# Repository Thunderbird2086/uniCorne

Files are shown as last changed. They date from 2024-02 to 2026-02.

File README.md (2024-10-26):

# uniCorne

uniCorne is inspired by [corne](foostatn/crkbd), and here are the key features of uniCorne:

1. **Controller Compatibility**: uniCorne is specifically tailored to work with ProMicro-like controllers such as [Nice!Nano](https://nicekeyboards.com/docs/nice-nano/), [Elite-Pi](https://docs.keeb.io/elite-pi-guide), and [Ble Micro Pro](https://sekigon-gonnoc.github.io/BLE-Micro-Pro/#/). This ensures seamless integration and optimal performance.
1. **Hardware Handedness**: Unlike many other keyboards, uniCorne supports hardware handedness for ProMicro-like RP2040 controller boards. This flexibility allows users to choose their preferred orientation without sacrificing functionality.
1. **Nice!View Integration**: uniCorne has been meticulously crafted to seamlessly integrate with [Nice!View](https://nicekeyboards.com/docs/nice-view/). Users can enjoy a cohesive experience without needing any modifications to the board.

In summary, uniCorne combines controller compatibility, hardware flexibility, and thoughtful integration, making it a standout choice for keyboard enthusiasts.

## Profiles
uniCorne offers three distinct flavors: standard profile, low profile, and hybrid profile.

### Standard Profile
Equipped with Cherry MX compatible switches, available in both 3-pin and 5-pin.<br>
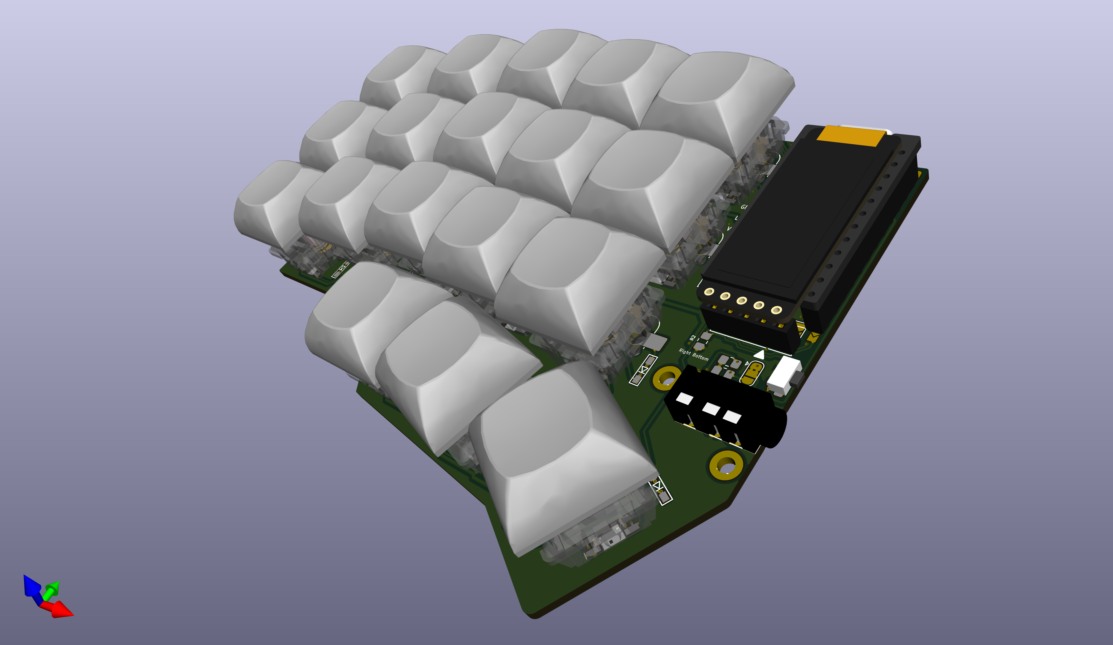
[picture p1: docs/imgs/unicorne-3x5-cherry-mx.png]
Standard Profile


### Low Profile
The low-profile variant primarily incorporates Kailh Low-Profile switches, supporting both Kailh Choc V1 and V2 switches.<br>
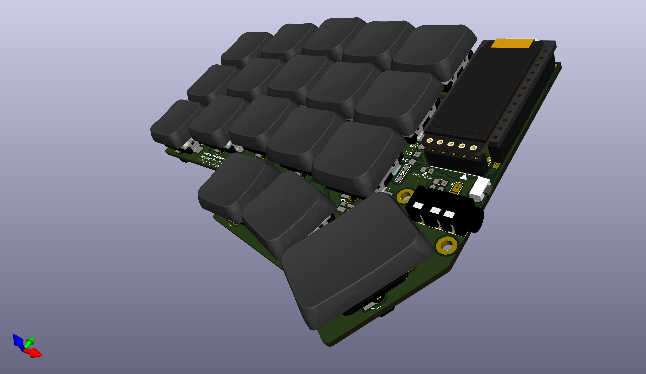
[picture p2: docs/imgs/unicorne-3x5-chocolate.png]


### Hybrid Profile
In the hybrid setup, low-profile switches are utilized for the thumb block, while standard-profile switches are employed for the remaining keys.<br>
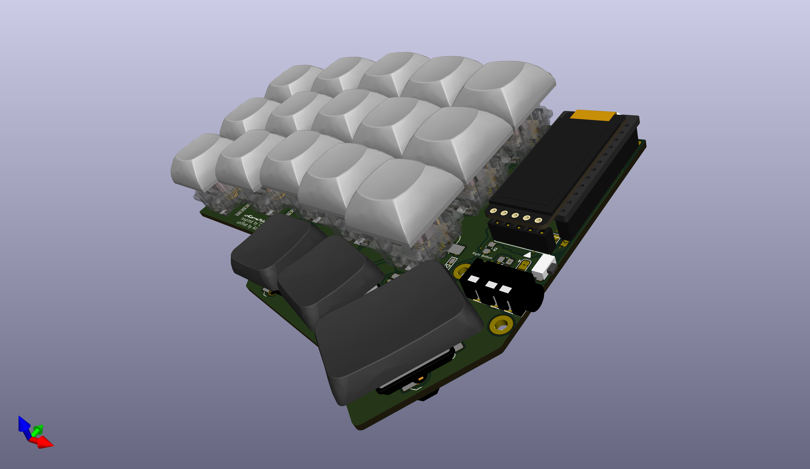
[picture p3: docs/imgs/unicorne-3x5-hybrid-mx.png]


## Variants
uniCorne is availabe in two enticing variations: 3x5 and 3x6.

The 3x6 variant caters to users who may not be accustomed to split keyboards, as its layout closely resembles that of standard keyboards. With 21 keys on each side, the 3x6 configuration boasts a total of 42 keys.<br>
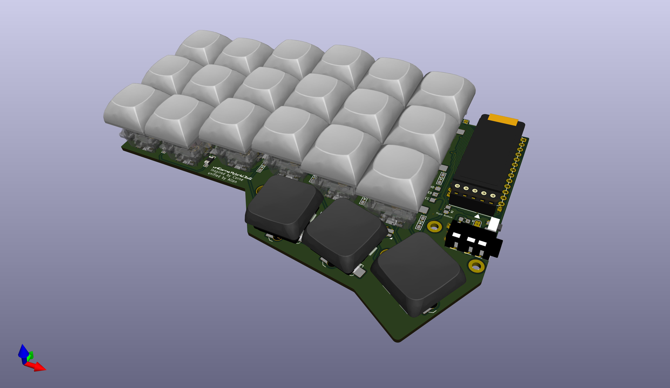
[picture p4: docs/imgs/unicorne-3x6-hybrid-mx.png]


On the other hand, the 3x5 variant provides a more streamlined option, with 18 keys on each side for a total of 36 keys.

## Build Guides
uniCorne 3x5 is used as an example. Refer to [the guides](https://thunderbird2086.github.io/uniCorne).

## fonts
 - [Android Robot](https://www.1001freefonts.com/android-robot.font)
 - [Avenir Next Heavy](https://en.maisfontes.com/avenir-next-heavy.font)
 - [Hack](https://www.1001freefonts.com/hack.font)

## firmwares
 - [QMK](https://github.com/Thunderbird2086/tb2086-qmk)
 - [ZMK](https://github.com/Thunderbird2086/unicorne-zmk-config)

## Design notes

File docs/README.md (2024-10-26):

# uniCorne Build Guide

## Materials Needed: 
- Common parts

  | **Component**        | **Quantity** | **Description**                                      |
  |---                   |---:          | ---                                                  |
  | PCB                  | 2            | Left and right side                                  |
  | Switches             | 36           | Mechanical switches (e.g., Cherry MX, Kailh Choc)    |
  | Keycaps              | 36           | Keycaps compatible with your switches                |
  | Hotswap Sockets      | 36           | Hotswap sockets compatible with your switches        |
  | 1N4148W SOD-123      | 36           | Diodes for each switch                               |
  | Tactile Push Button  | 1            | SMD 2x4x3.5mm                                        |
  | Top Plate            | 1            | Case compatible with uniCorne-3x5 PCB                |
  | Bottom Plate         | 1            | Plate compatible with uniCorne-3x5 PCB               |
  | M2x4 Screw           | 20           | Screws for assembling the case                       |
  | M2x6 Standoff        | 10           | Spacers for assembling the case                      |

- Wired or Wireless
  - Wired keyboard

    | **Component**        | **Quantity** | **Description**                                      |
    |---                   |---:          | ---                                                  |
    | MCU                  | 2            | Promicro-ish e.g. Promicro, Elite-Pi, etc.           |
    | TRRS Sockets         | 2            | For connecting the two halves of keyboard            |
    | TRRS Cable           | 1            | Cable to connect the two halves of keyboard          |

  - Wireless keyboard

    | **Component**        | **Quantity** | **Description**                                      |
    |---                   |---:          | ---                                                  |
    | MCU                  | 2            | Promicro-ish NRF52480 board e.g. [nice!nano](https://nicekeyboards.com/nice-nano)           |
    | MSK-12C02 SMD        | 2            | Power switch for wireless                            |
    | Pico-EZmate 78171 2P | 2            | 2P socket for battery                                |

- Optional parts<br>

  | **Component**        | **Quantity** | **Description**                                        |
  |---                   |---:          | ---                                                    |
  | OLED Screen          | 1            | For displaying information, 128x32                     |
  | Tenting Kit          | 1            | For ergonomic typing angle                             |

  - Wired keyboard

    | **Component**        | **Quantity** | **Description**                                      |
    |---                   |---:          | ---                                                  |
    | SK6812 mini-e        | 30           | For per-key LED                                      |
    | SK6812 mini 3535     | 6            | For backlight LED                                    |
    | 10k SMD2012(metric)  | 2            | For handedness for wired keyboard                    |
    | 4.7k SMD2012(metric) | 2            | For I2C communication for wired keyboard             |

## Step-by-Step Guide:
1. Before starting:<br>
   uniCorne is designed to be soldered only on the bottom side.
1. Align PCBs:<br>
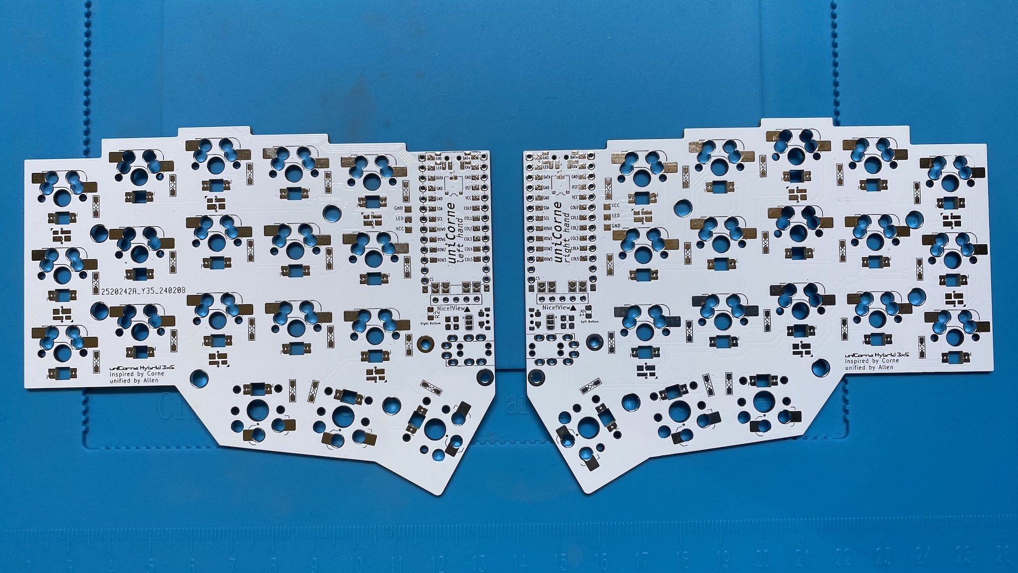
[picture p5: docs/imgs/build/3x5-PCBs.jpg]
PCBs
   <br>
   Theres is a marking on top side indicating the correct side.<br>
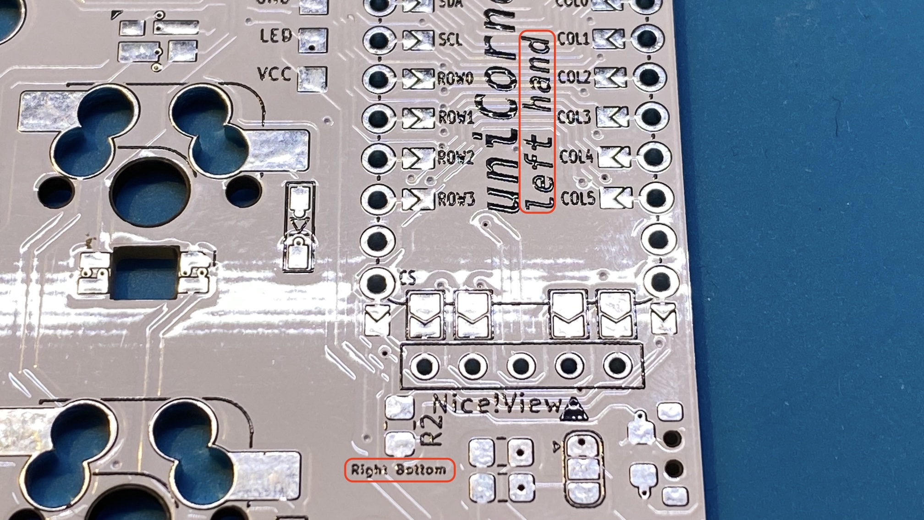
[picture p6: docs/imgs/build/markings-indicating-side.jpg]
Markings indicating side
   
1. Hotswaps:<br>
   Place the hot-swappable sockets on the PCB, and make sure it align with the holes on the PCB. Then, solder it.<br>
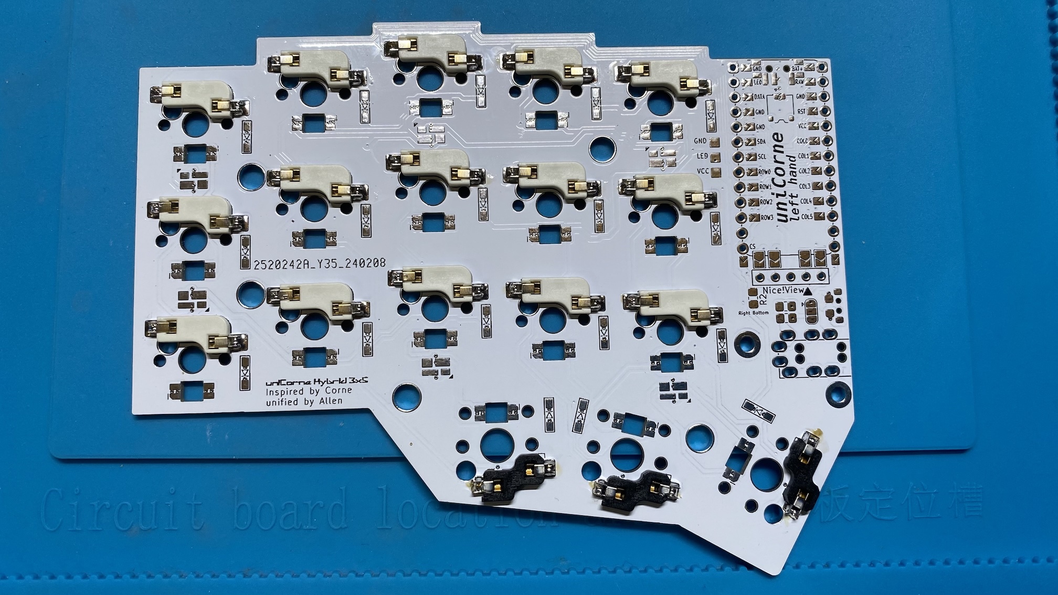
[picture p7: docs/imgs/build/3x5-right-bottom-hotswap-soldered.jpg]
Hotswap soldered
   
1. Diodes:<br>
   Diodes have markings to indicate the direction.  Make sure they are aligned with slikscreen.<br>
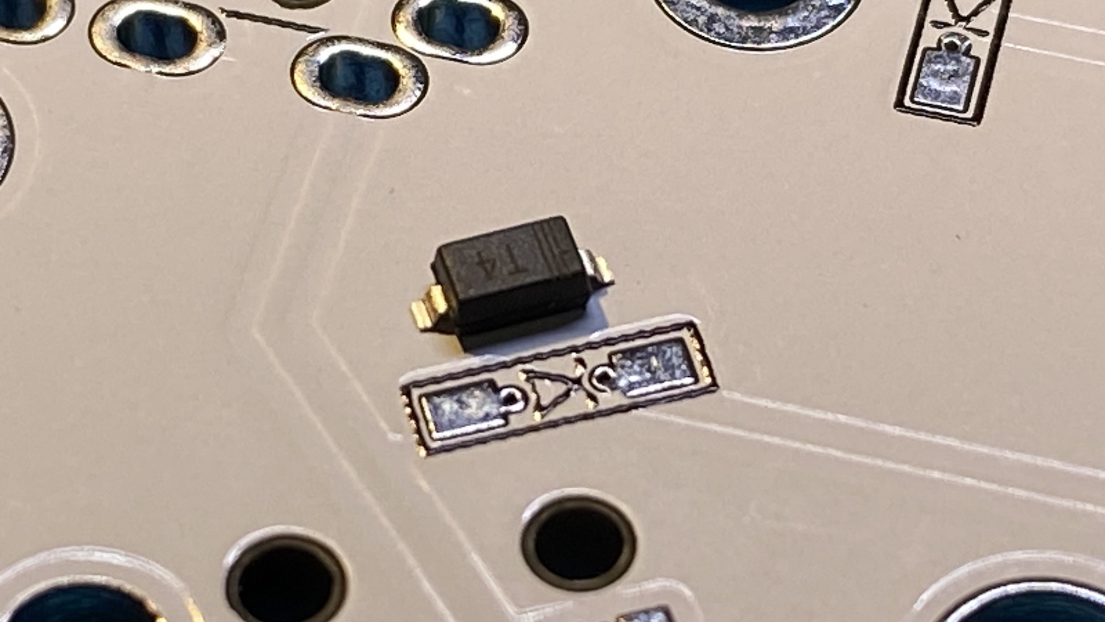
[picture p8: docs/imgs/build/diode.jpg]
diode marking
   
1. MCU
   1. Solder jumpers for MCU on the bottom side.<br>
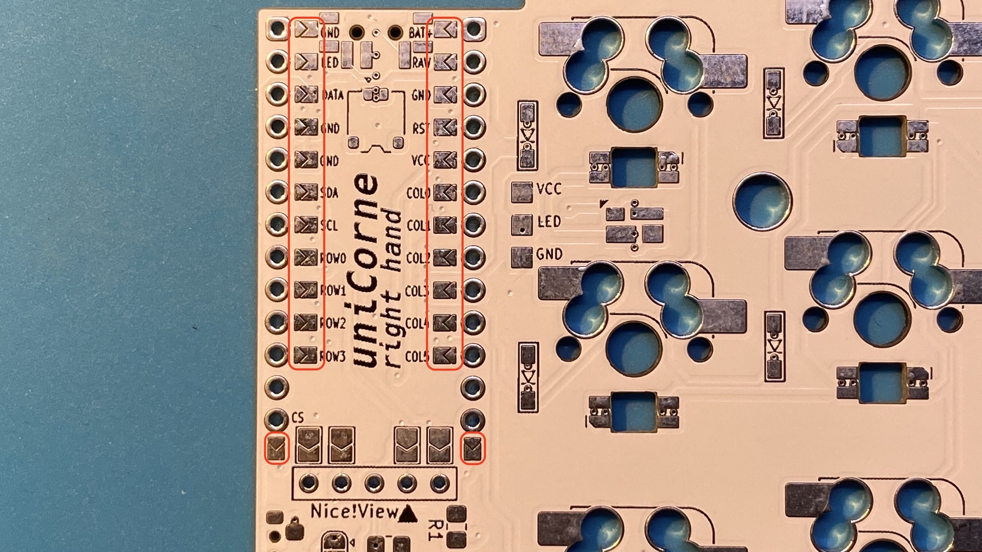
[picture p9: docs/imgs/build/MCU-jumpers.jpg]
MCU jumbers
      
   1. Solder pin sockets which allows you to replace MCUs later.<br>
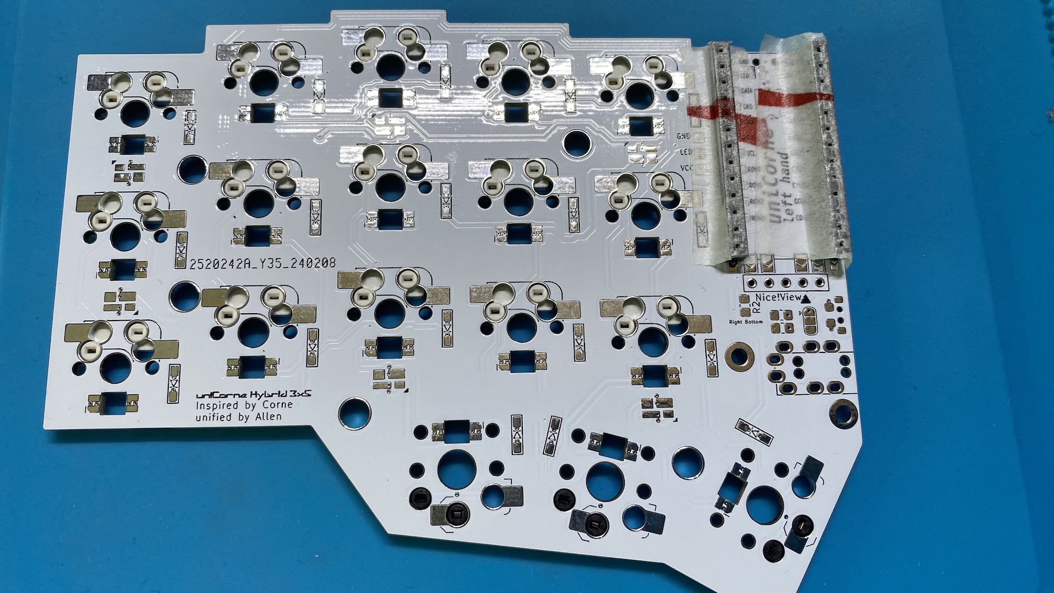
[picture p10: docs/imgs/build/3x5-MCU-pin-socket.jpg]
MCU pin sockets
      
   1. Place the MUC on pin sockets and insert pin headers.<br>
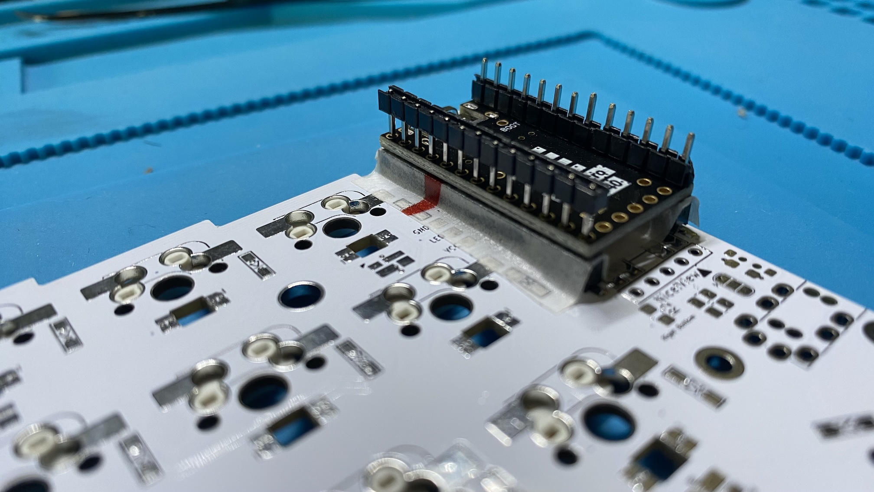
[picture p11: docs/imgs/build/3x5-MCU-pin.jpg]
      
   1. Cut the pin header for one side once everything is aligned.<br>
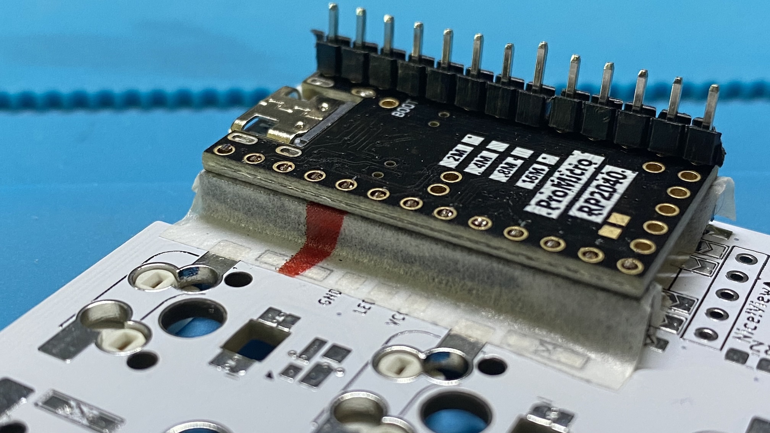
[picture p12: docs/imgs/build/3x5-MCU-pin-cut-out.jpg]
      
   1. Solder one side and repeat for the other side. The result should look like this when done.<br>
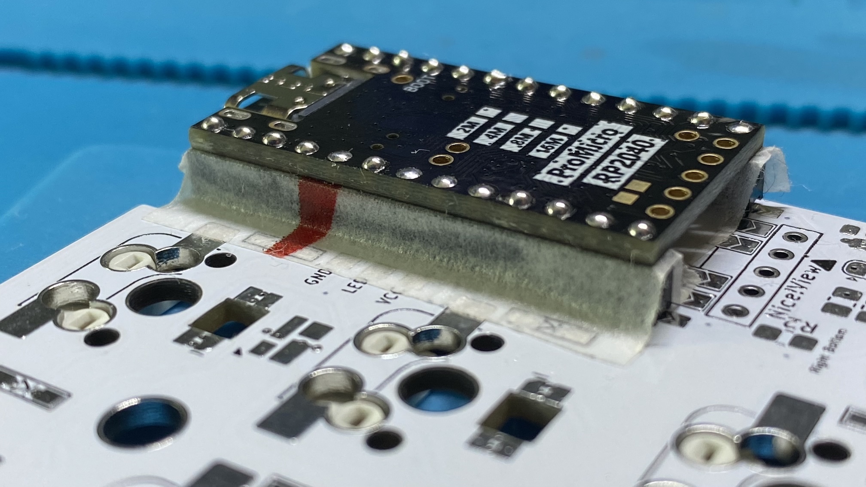
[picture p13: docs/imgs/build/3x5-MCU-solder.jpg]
MCU soldered
      
1. TRRS Socket:<br>
   Solder TRRS socket.<br>
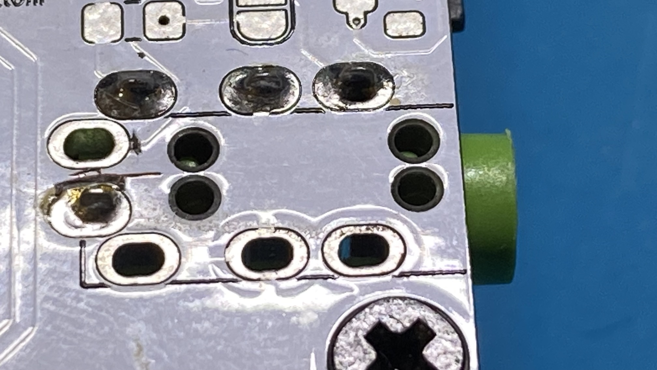
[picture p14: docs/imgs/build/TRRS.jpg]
   
1. Test the PCB:<br>
   Before fully assembling, test the PCB to ensure all switches work correctly after installing the relavant [firmware](https://github.com/Thunderbird2086/tb2086-qmk/releases). You can use a keyboard tester software for this e.g. QMK Toolbox.
1. Optional parts:
   - LEDs:<br>
     Solder LEDs.  There are two types: one for per-key lighting and the other for backlighting.<br>
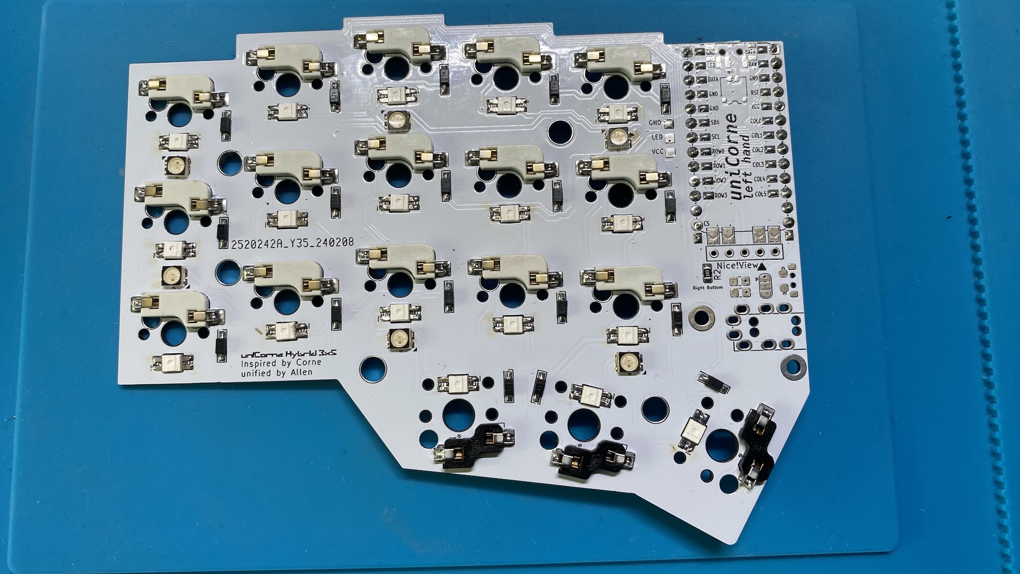
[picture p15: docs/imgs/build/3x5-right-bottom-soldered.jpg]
LEDs
     
   - OLED Screen:<br>
     If you have an OLED screen, solder jumpers for OLED as well as 5-pin socket on the bottom side.<br>
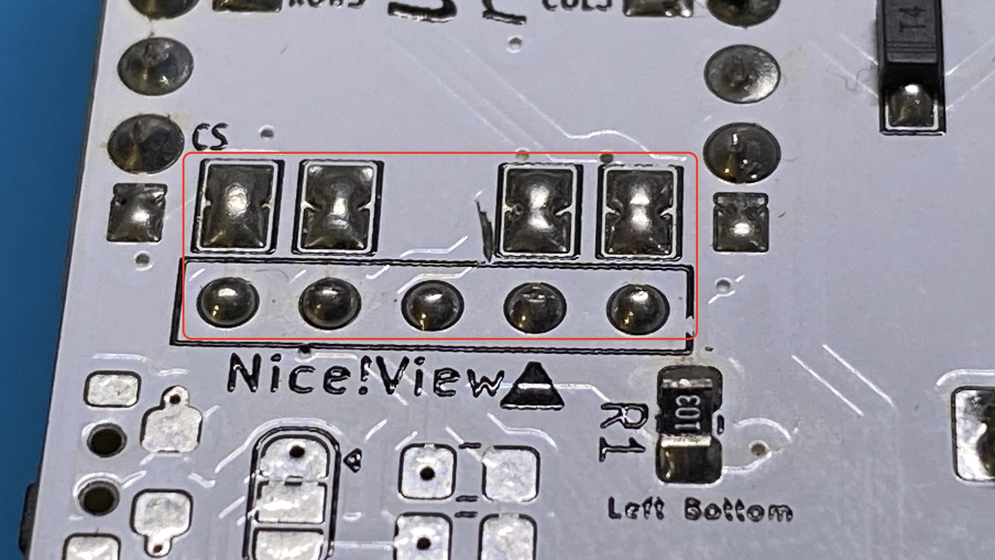
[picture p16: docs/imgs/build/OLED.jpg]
OLED
     
   - Hardware Handedness:<br>
     If you want to use hardware handedness, solder the handedness resitor on the bottom side.<br>
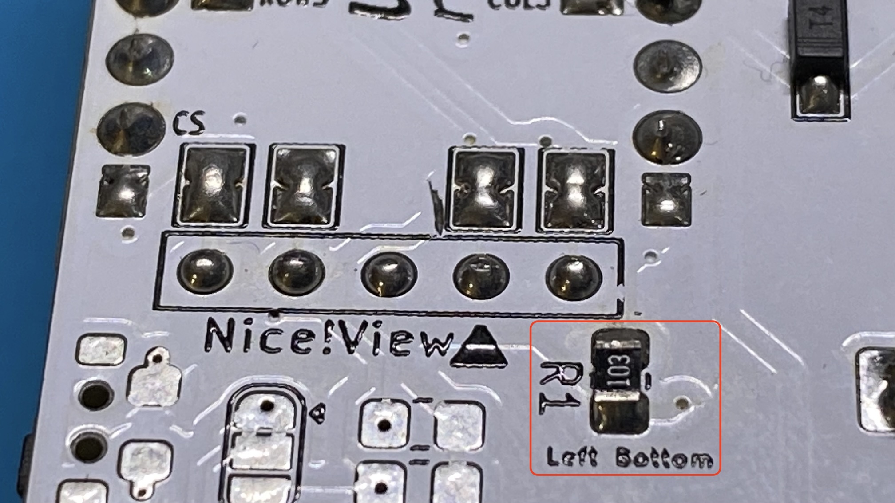
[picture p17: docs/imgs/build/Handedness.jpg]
Hardware Handedness
     
1. Assemble:<br>
   Place top plate, the PCB, and the bottom plate. Then, secure them with screws.
1. Add Keycaps:<br>
   Place your keycaps onto the switches. Ensure they are firmly seated.
1. Install Tenting Kit (optional):<br>
   If you have a tenting kit, attach it to the bottom of the case for an ergonomic typing angle.
1. Final Check:<br>
   Double-check all connections and ensure everything is securely in place.<br>
   Test the keyboard again to ensure all keys are functioning properly.
1. Enjoy Your New Keyboard:<br>
   Customize your keymap and enjoy typing on your new uniCorne-3x5 keyboard!

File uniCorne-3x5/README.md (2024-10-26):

# uniCorne 3x5

* cherry-mx-reversible : Standard Profile<br>
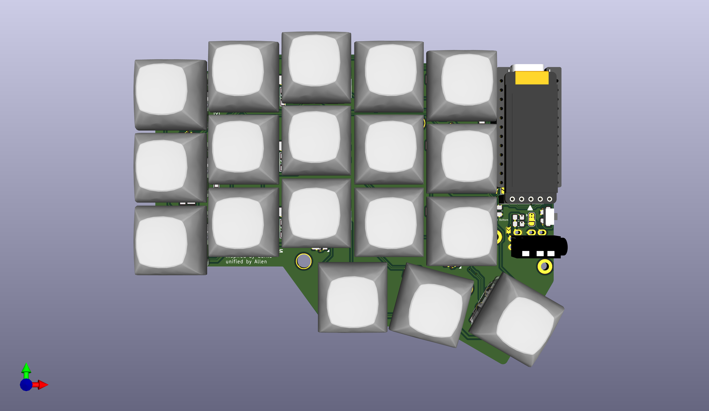
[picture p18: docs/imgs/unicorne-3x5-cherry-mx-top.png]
  

* chocolate-reversible : Low Profile<br>
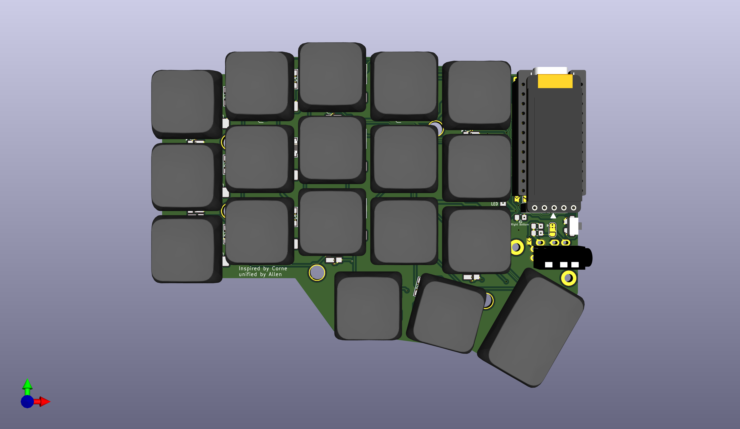
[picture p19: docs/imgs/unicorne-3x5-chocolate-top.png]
  

* mybrid-mx-reversible : Hybrid Profile<br>
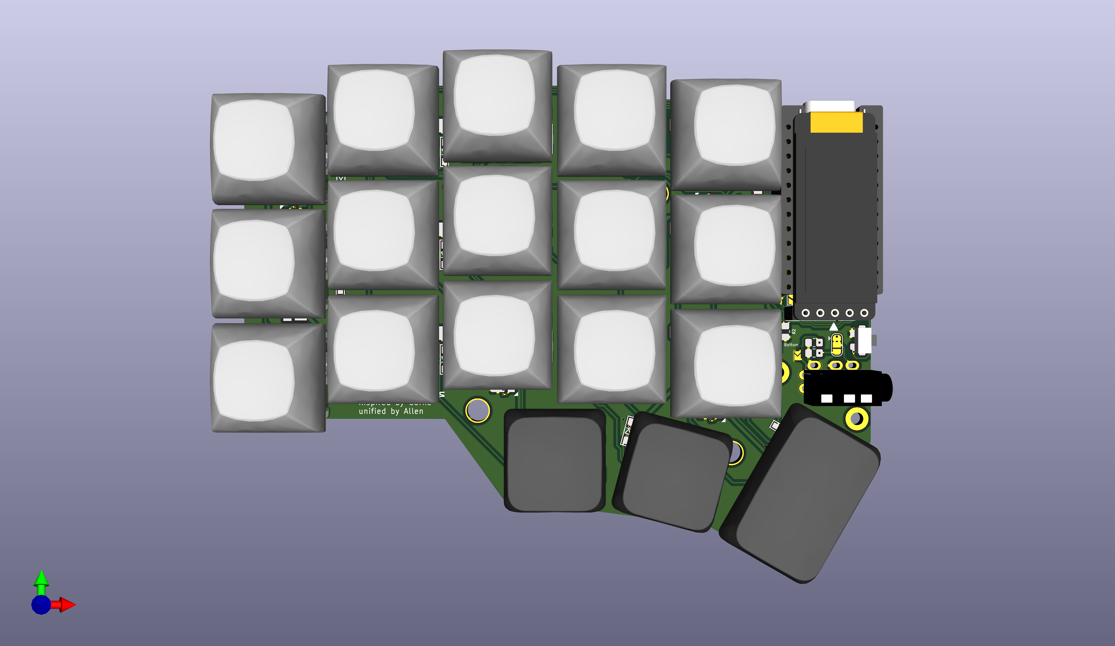
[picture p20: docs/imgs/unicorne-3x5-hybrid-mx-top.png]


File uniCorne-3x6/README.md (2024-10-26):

# uniCorne 3x6

* cherry-mx-reversible : Standard Profile<br>
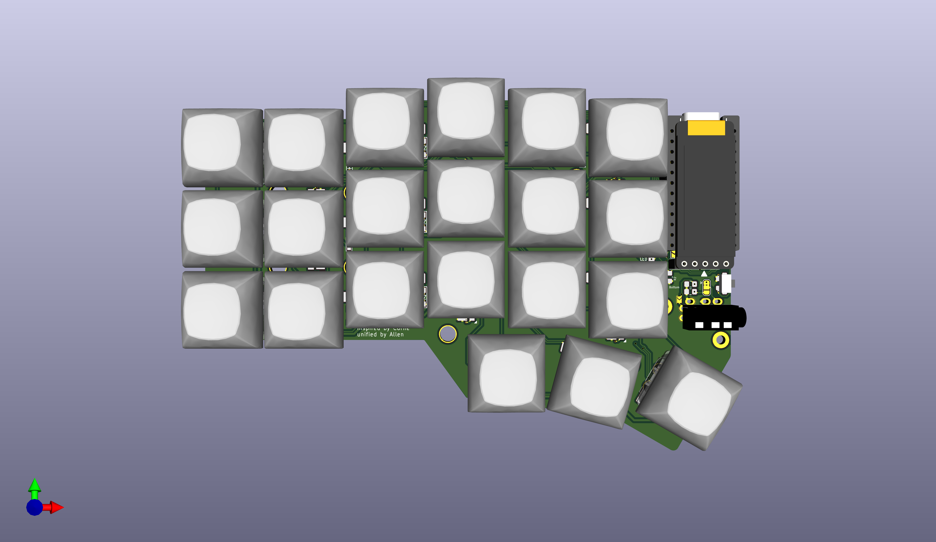
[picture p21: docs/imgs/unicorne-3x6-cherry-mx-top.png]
  

* chocolate-reversible : Low Profile<br>
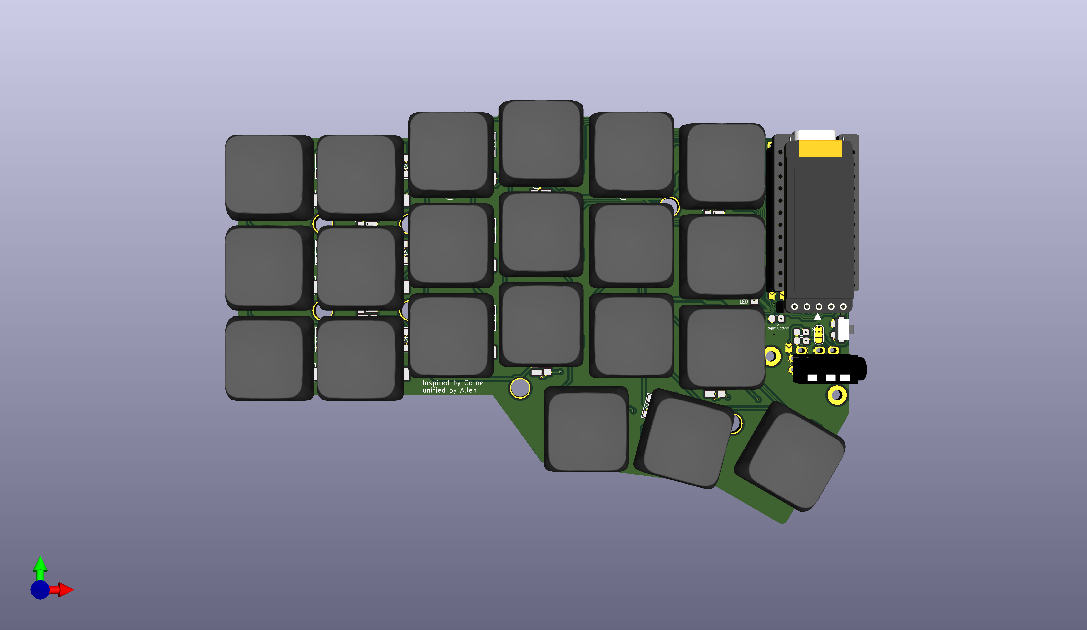
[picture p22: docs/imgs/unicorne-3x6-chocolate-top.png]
  

* mybrid-mx-reversible : Hybrid Profile<br>
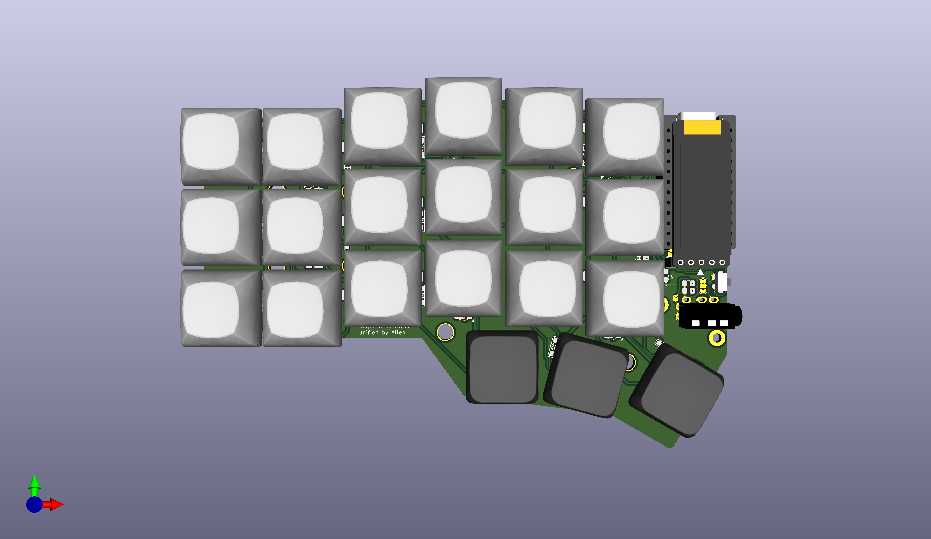
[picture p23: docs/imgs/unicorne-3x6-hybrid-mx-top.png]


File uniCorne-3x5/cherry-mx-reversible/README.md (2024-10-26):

# uniCorne 3x5 Standard Profile

## Top
uniCorne 3x5 Standard Profile Top

## Bottom
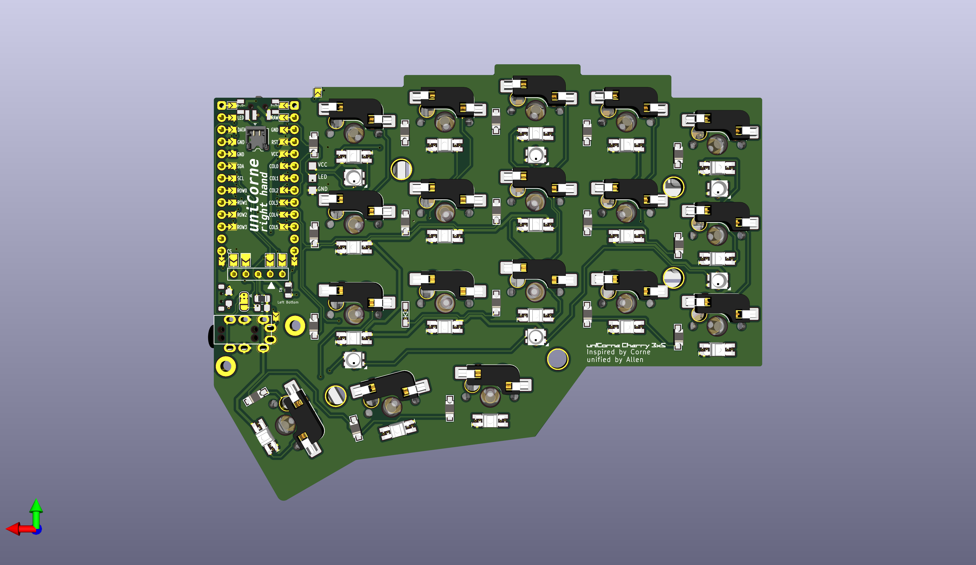
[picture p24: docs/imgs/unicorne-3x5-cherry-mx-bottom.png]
uniCorne 3x5 Standard Profile Top


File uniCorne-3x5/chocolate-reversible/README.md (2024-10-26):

# uniCorne 3x5 Low Profile

## Top
uniCorne 3x5 Low Profile Top

## Bottom
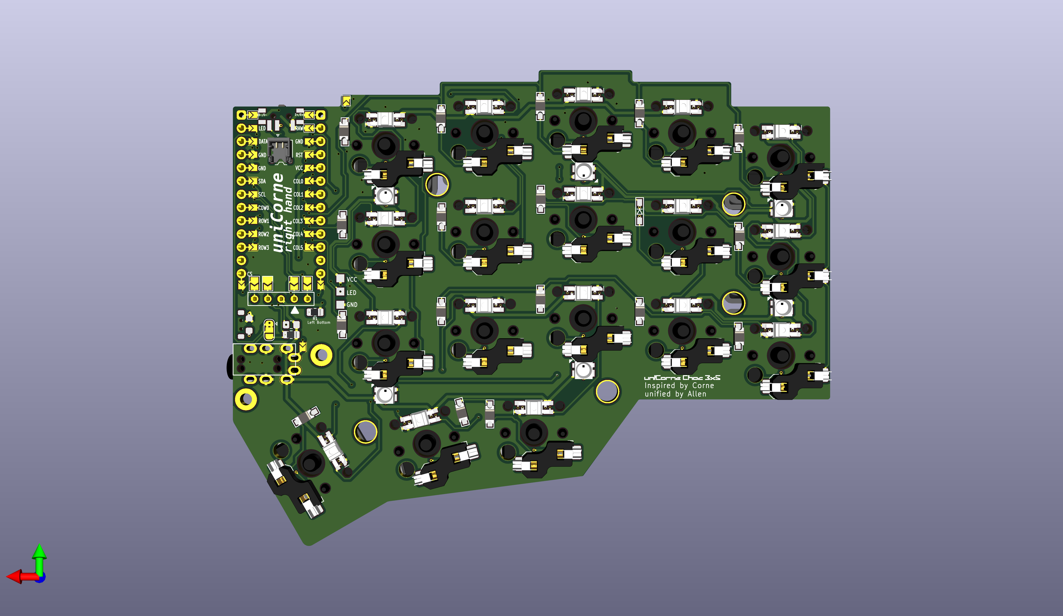
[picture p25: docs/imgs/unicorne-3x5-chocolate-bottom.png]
uniCorne 3x5 Low Profile Top


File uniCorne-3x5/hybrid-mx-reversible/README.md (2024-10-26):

# uniCorne 3x5 Hybrid Profile

## Top
uniCorne 3x5 Hybrid Profile Top

## Bottom
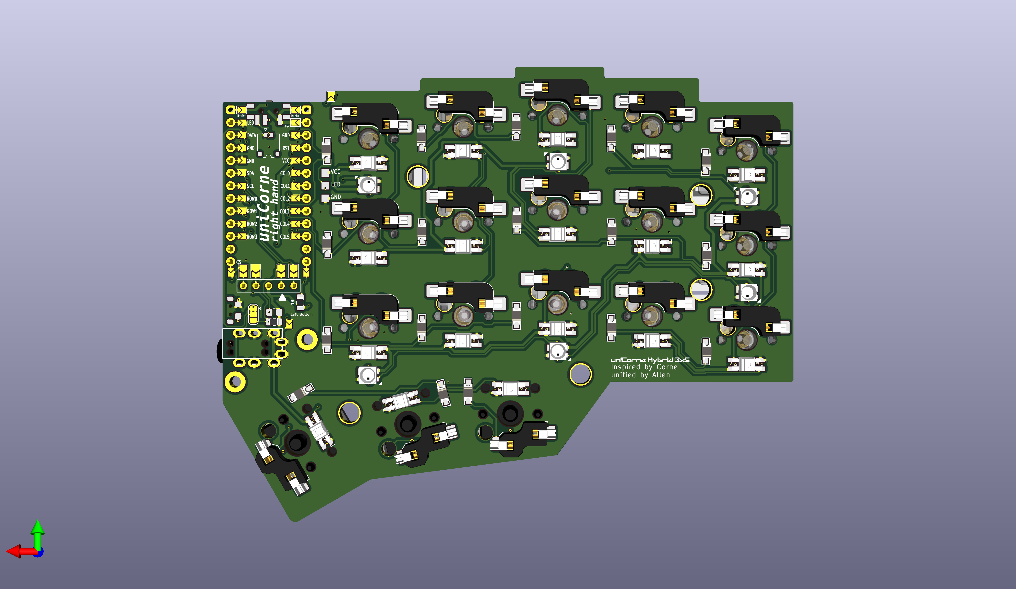
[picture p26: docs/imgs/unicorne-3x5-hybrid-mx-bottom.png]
uniCorne 3x5 Hybrid Profile Top


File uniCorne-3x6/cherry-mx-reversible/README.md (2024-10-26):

# uniCorne 3x6 Standard Profile

## Top
uniCorne 3x6 Standard Profile Top

## Bottom
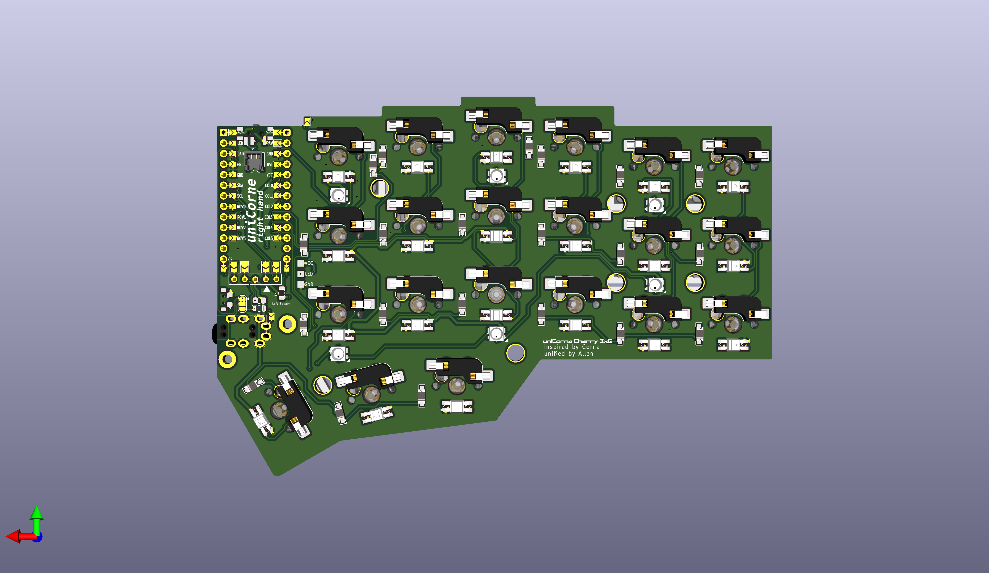
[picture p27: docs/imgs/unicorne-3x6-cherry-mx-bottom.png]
uniCorne 3x6 Standard Profile Top


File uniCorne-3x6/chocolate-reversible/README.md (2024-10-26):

# uniCorne 3x6 Low Profile

## Top
uniCorne 3x6 Low Profile Top

## Bottom
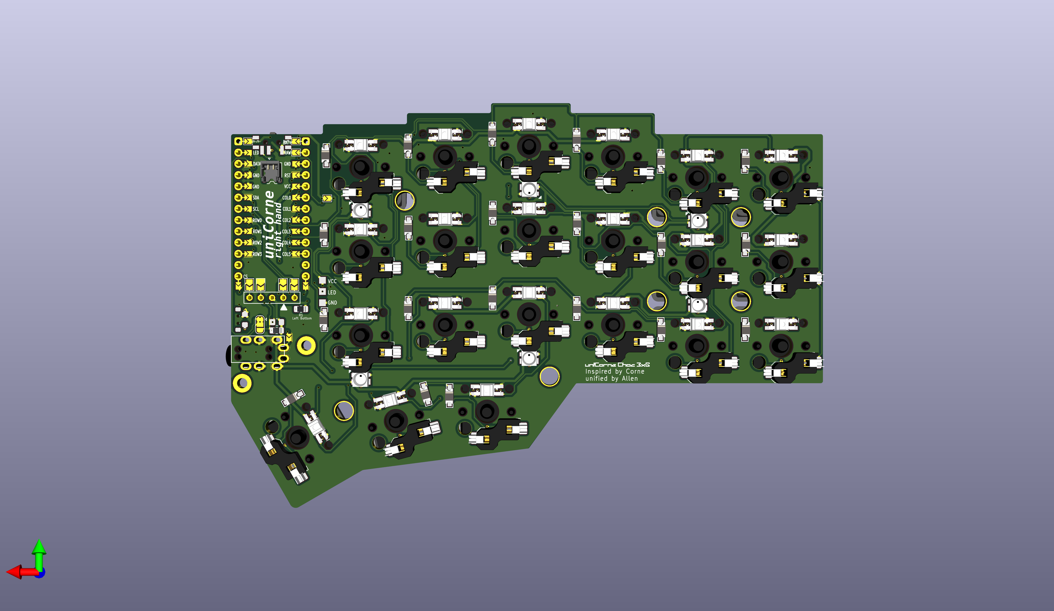
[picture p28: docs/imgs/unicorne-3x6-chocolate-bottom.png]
uniCorne 3x6 Low Profile Top


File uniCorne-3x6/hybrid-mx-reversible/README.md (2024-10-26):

# uniCorne 3x6 Hybrid Profile

## Top
uniCorne 3x6 Hybrid Profile Top

## Bottom
uniCorne 3x6 Hybrid Profile Top

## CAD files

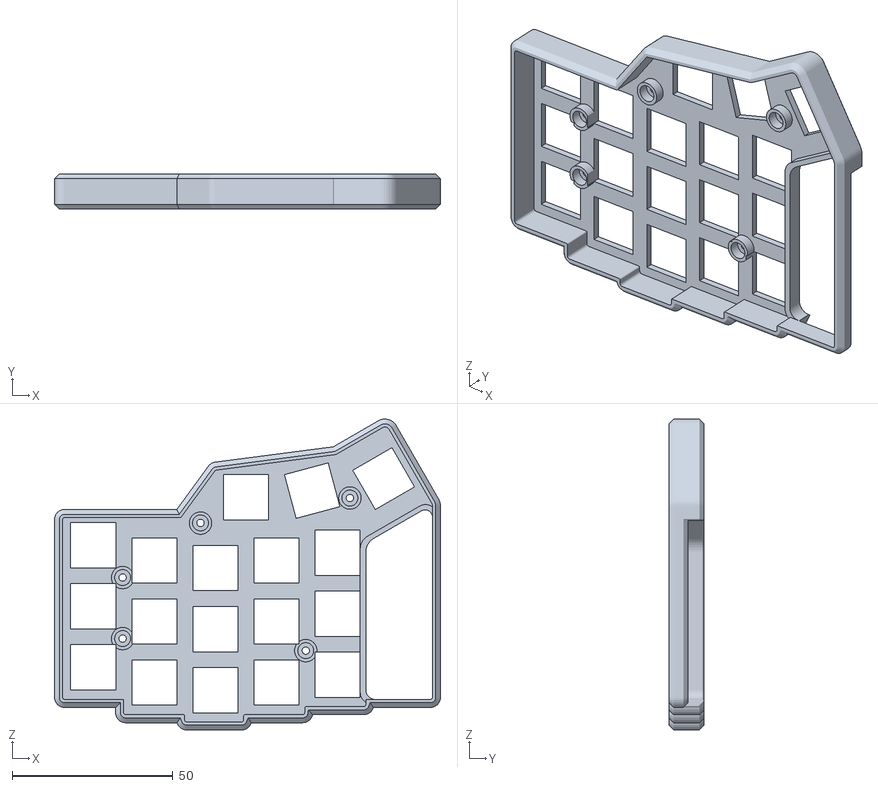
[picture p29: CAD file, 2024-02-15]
case/3d-printing/3x5/uniCorne-cherry-mx-3x5-left.stl
120.2 x 11.0 x 96.8

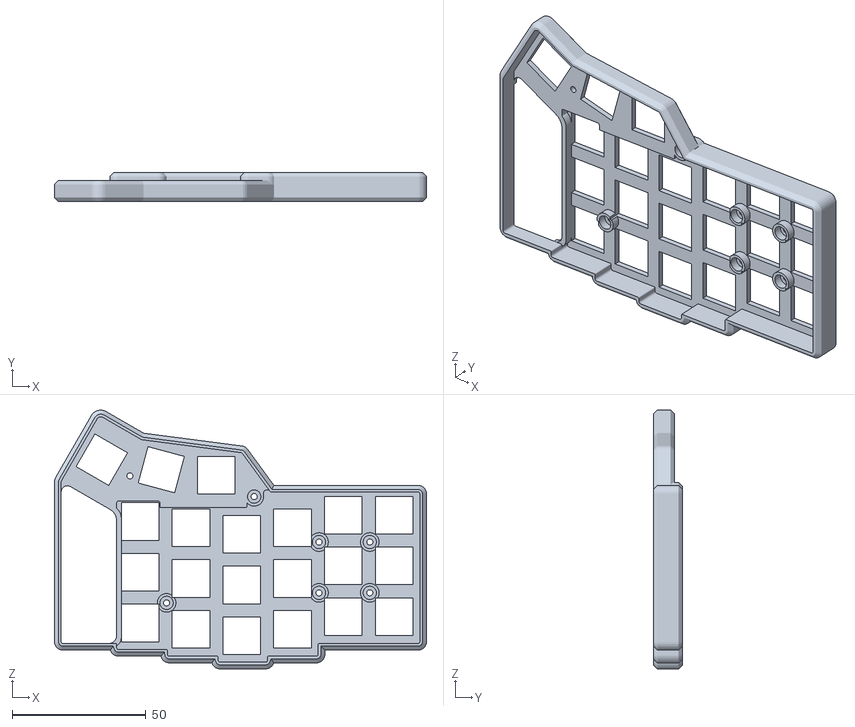
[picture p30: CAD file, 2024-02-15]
case/3d-printing/3x6/uniCorne-hybrid-mx-3x6-right.stl
139.2 x 11.0 x 96.8

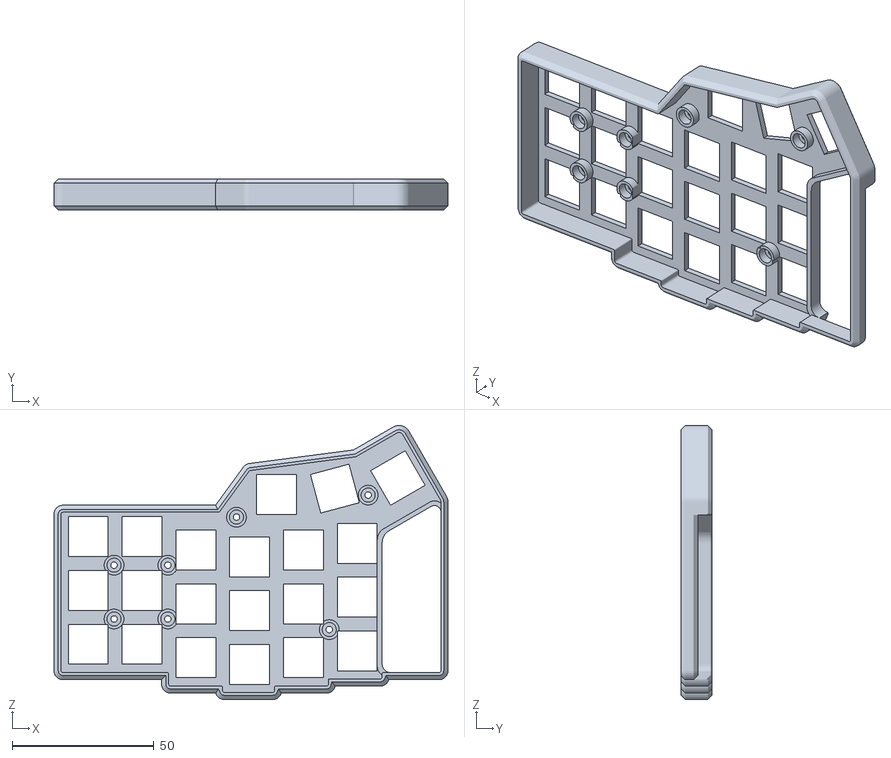
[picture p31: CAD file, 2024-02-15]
case/3d-printing/3x6/uniCorne-cherry-mx-3x6-left.stl
139.2 x 11.0 x 96.8

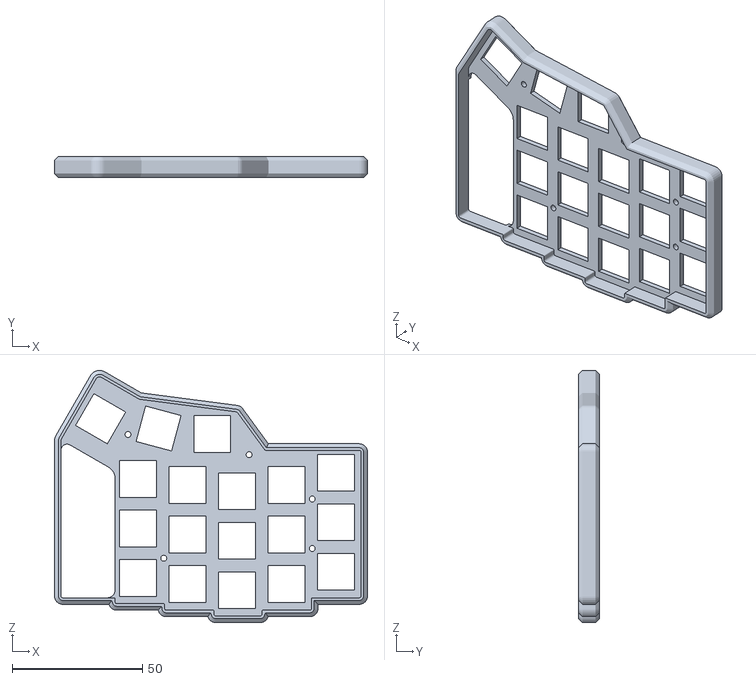
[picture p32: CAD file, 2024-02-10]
case/3d-printing/3x5/uniCorne-chocolate-3x5-right.stl
120.2 x 8.00 x 96.8

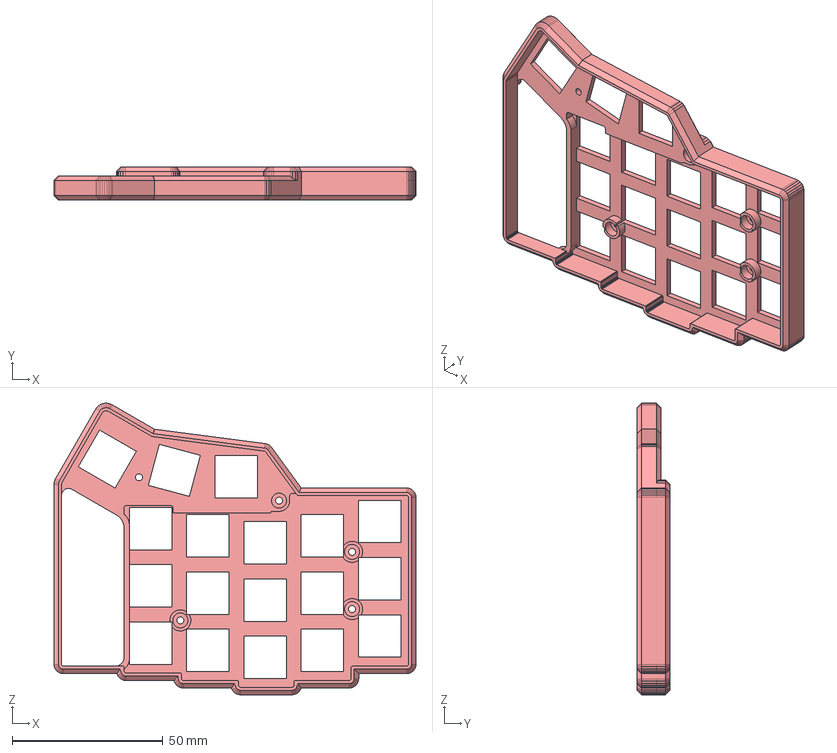
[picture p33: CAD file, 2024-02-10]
case/cnc/3x5/uniCorne-hybrid-mx-3x5-right.step
120.2 x 11.0 x 96.8 mm

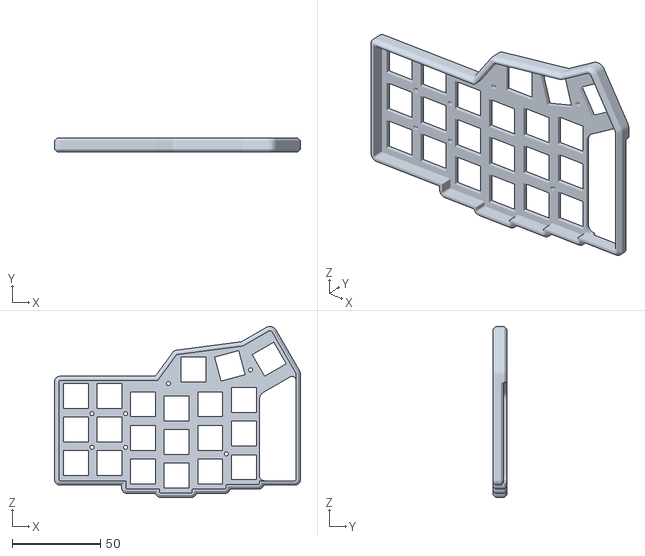
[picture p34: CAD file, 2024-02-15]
case/3d-printing/3x6/uniCorne-chocolate-3x6-left.stl
139.2 x 8.00 x 96.8

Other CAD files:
case/cnc/3x5/uniCorne-cherry-mx-3x5-left.step
case/cnc/3x6/uniCorne-hybrid-mx-3x6-right.step
case/3d-printing/3x5/uniCorne-cherry-mx-3x5-right.stl
case/cnc/3x5/uniCorne-cherry-mx-3x5-right.step
case/cnc/3x6/uniCorne-cherry-mx-3x6-right.step
case/3d-printing/3x6/uniCorne-cherry-mx-3x6-right.stl
case/cnc/3x6/uniCorne-cherry-mx-3x6-left.step
case/3d-printing/3x5/uniCorne-hybrid-mx-3x5-left.stl
case/cnc/3x5/uniCorne-chocolate-3x5-right.step
case/cnc/3x6/uniCorne-chocolate-3x6-right.step
case/3d-printing/3x5/uniCorne-hybrid-mx-3x5-right.stl
case/3d-printing/3x6/uniCorne-chocolate-3x6-right.stl
case/3d-printing/3x5/uniCorne-chocolate-3x5-left.stl
case/3d-printing/3x6/uniCorne-hybrid-mx-3x6-left.stl
case/cnc/3x5/uniCorne-chocolate-3x5-left.step
case/cnc/3x5/uniCorne-hybrid-mx-3x5-left.step
case/cnc/3x6/uniCorne-chocolate-3x6-left.step
case/cnc/3x6/uniCorne-hybrid-mx-3x6-left.step
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

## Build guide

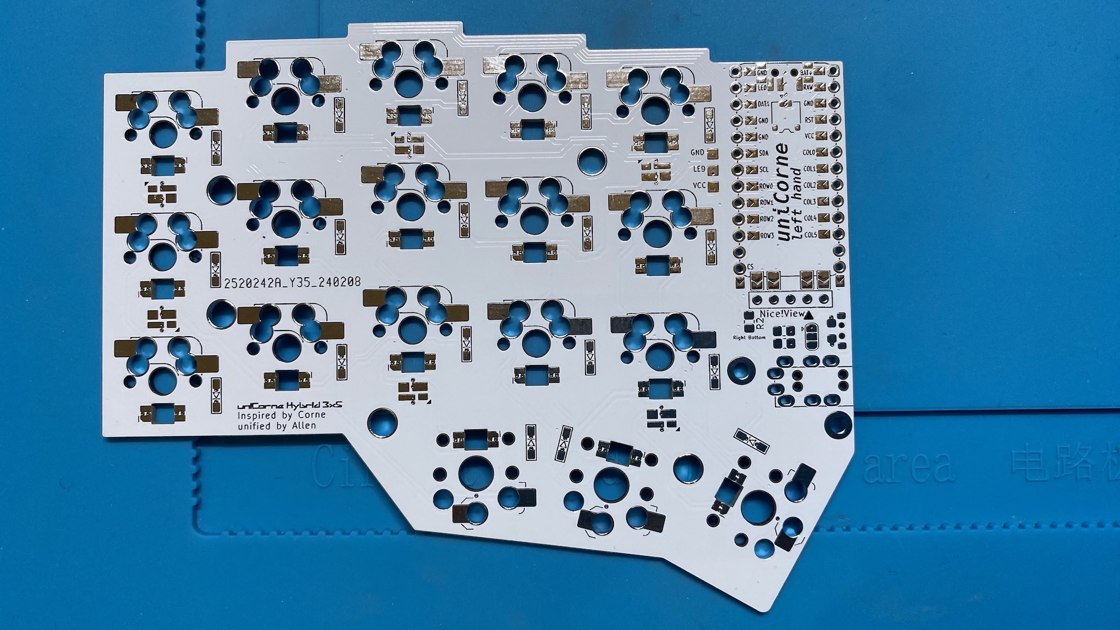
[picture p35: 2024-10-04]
docs/imgs/build/3x5-right-bottom.jpg

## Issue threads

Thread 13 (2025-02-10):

Questions

zigapk, 2025-02-10:
Hi there!

Wonderful project - thank you for publishing all of the files here.

I am looking to build a MX/hybrid wireless uniCorne and have a few questions and was wondering whether you could provide some further details:

1. Where is the wireless power switch supposed to go? I could not determine this from the PCB blueprints.
2. I'd like to CNC an aluminum case and found the files have a 2mm "top plate" thickness. The internet leads me to believe that it should be 1.5mm - is this on purpose?
3. When using the CNC case, what thickness is the bottom plate supposed to be?

Thank you so much!

zigapk, 2025-02-14:
@Thunderbird2086 just a ping in case you missed this - I'll stop bothering you afterwards 😄

Thunderbird2086, 2025-02-16:
@zigapk thanks for reaching out me and sorry for the delayed response as I am traveling now.

> 1. Where is the wireless power switch supposed to go? I could not determine this from the PCB blueprints.

   I gave freedom to people in caes of their own case design.  However, it should be front side as same as key switches if you are going to use one of the cases from my repo.

> 2. I'd like to CNC an aluminum case and found the files have a 2mm "top plate" thickness. The internet leads me to believe that it should be 1.5mm - is this on purpose?

  Yes, I gave it 2mm as same as acrylic plate.  I think 1.5mm should be fine

> 3. When using the CNC case, what thickness is the bottom plate supposed to be?

  I did not design CNCed bottom plate as I want to use acrylic one.

Closed 2025-06-16.

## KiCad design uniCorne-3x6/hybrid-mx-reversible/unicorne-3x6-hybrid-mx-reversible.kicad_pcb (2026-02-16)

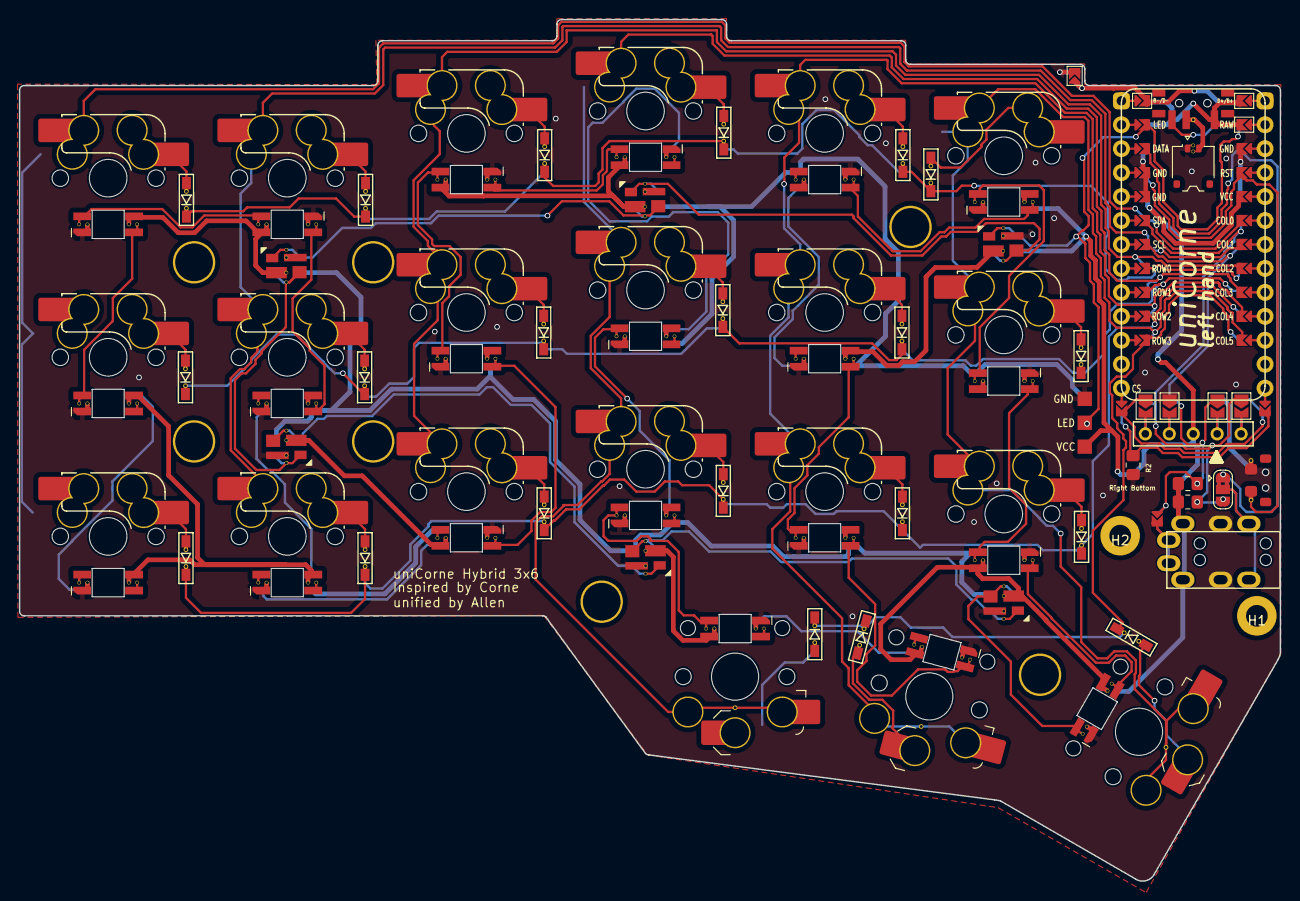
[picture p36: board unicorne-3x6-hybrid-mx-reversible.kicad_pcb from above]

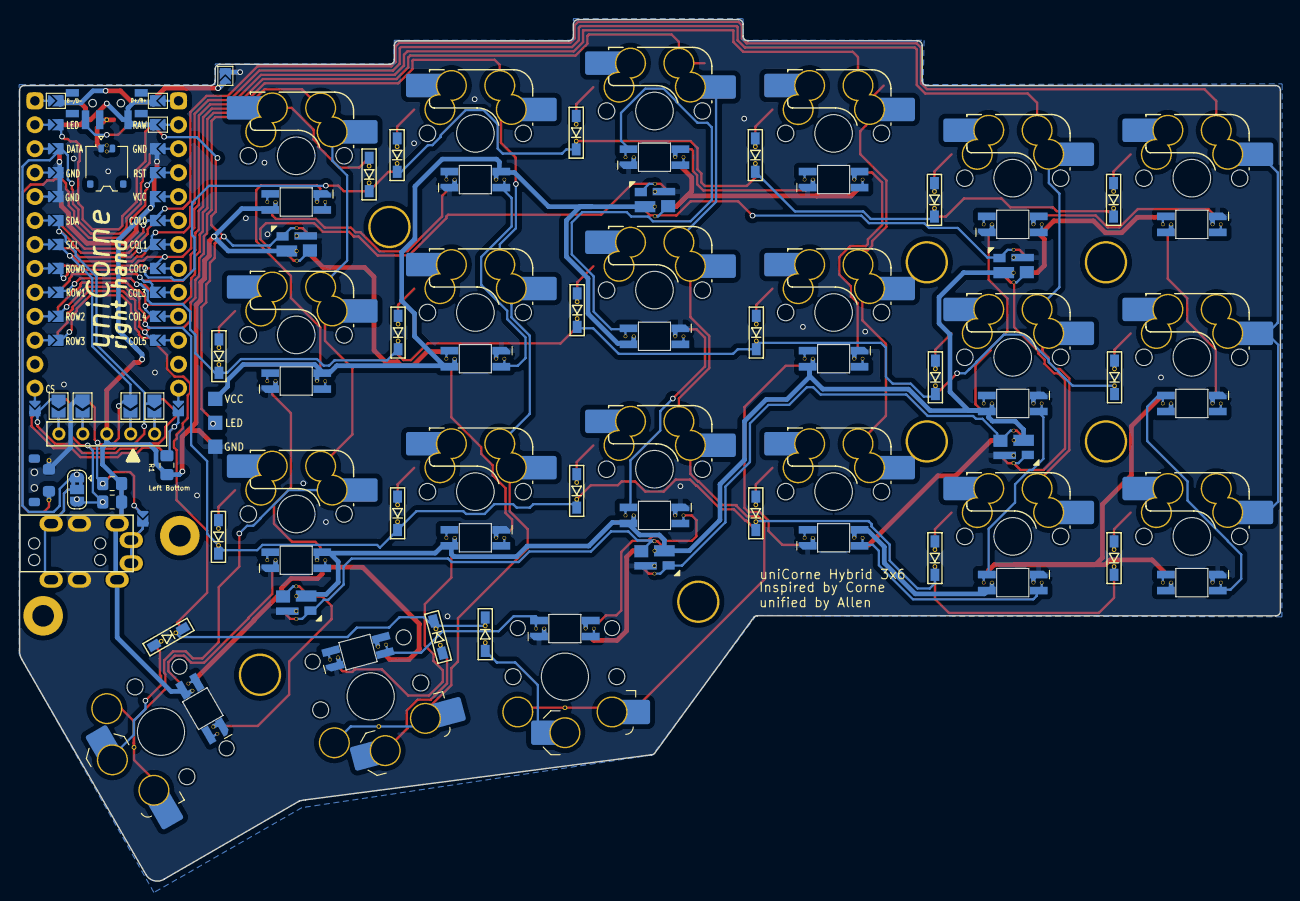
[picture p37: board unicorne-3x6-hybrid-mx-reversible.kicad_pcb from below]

Board: 2 copper layers, 133.8 x 91.4 mm, 100 parts (33 on the bottom side), 75 nets.

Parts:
D1, D2, D3, D4, D5, D6, D7, D8, D9, D10, D11, D12, D13, D14, D15, D16, D17, D18, D19, D20, D21: D; D3_SMD_rev
H1, H2: MountingHole; M2_Hole_TH
H3, H4, H5, H6, H7, H8, H9: MountingHole; M2_Hole_TH_Outside
J1: MJ-4PP-9; TRRS-PJ-320A-rev
J2: Nice!View
J3: Conn_01x02; Molex_Pico-EZmate_78171-0002_1x02-1MP_P1.20mm_Vertical_rev
J4: Conn_01x03; StripLED_rev
JP1, JP2, JP3, JP4, JP5, JP6, JP7, JP8: SolderJumper-2_P1.3mm_Open_TrianglePad1.0x1.5mm
JP9, JP11: SolderJumper-2_P1.3mm_Open_TrianglePad1.0x1.2mm_rev
JP10: Jumper_3_Bridged12; SolderJumper-3_P1.3mm_Bridged2Bar12_RoundedPad1.0x1.5mm_rev
L1, L2, L3, L4, L5, L6, L7, L8, L9, L10, L11, L12, L13, L14, L15, L16, L17, L18, L19, L20, L21: SK6812MINI-E; LED_SK6812MINI-E_rev
L22, L23, L24, L25, L26, L27: SK6812MINI; LED_SK6812MINI_PLCC4_3.5x3.5mm_P1.75mm_rev_all
PSW1: SW_SPDT; SW_SPDT_PCM12_reversible
R1, R2: 10k; R_0805_2012Metric_Pad1.20x1.40mm_HandSolder
R3, R4: 4.7k; R_0805_2012Metric_Pad1.20x1.40mm_HandSolder_rev
RSW1: SW_PUSH; SMT 2X4X3.5MM Tactile Tact Push Button rev
SW1, SW2, SW3, SW4, SW5, SW6, SW7, SW8, SW9, SW10, SW11, SW12, SW13, SW14, SW15, SW16, SW17, SW18: SW_MX_HS; SW_MX_HS_1u_reversible
SW19: SW_CHOC_HS; SW_choc_v1_v2_HS_1u_reversible
SW20, SW21: SW_CHOC_HS; SW_choc_v1_v2_HS_1.5u_reversible
U1: ProMicro-ish; ProMicro-ish-dn-rev-unrouted_3x6

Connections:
B-/D-: JP11.1 (A), U1.26 (B-/D-)
BAT+: PSW1.1 (A), U1.24 (RAW), U1.25 (D+/B+)
CS: JP1.1 (A), JP8.1 (A), U1.12 (B5)
DATA: JP10.1 (A), U1.2 (RX)
GND: J1.C, J3.1, J4.1, JP2.1 (A), JP7.1 (A), JP11.2 (B), L1.3 (VSS), L2.3 (VSS), L3.3 (VSS), L4.3 (VSS), L5.3 (VSS), L6.3 (VSS), L7.3 (VSS), L8.3 (VSS), L9.3 (VSS), L10.3 (VSS), L11.3 (VSS), L12.3 (VSS), L13.3 (VSS), L14.3 (VSS), L15.3 (VSS), L16.3 (VSS), L17.3 (VSS), L18.3 (VSS), L19.3 (VSS), L20.3 (VSS), L21.3 (VSS), L22.2 (VSS), L23.2 (VSS), L24.2 (VSS), L25.2 (VSS), L26.2 (VSS), L27.2 (VSS), R2.1, RSW1.1, U1.3 (GND), U1.4 (GND), U1.23 (GND)
IS_LEFT: R1.2, R2.2, U1.13 (B6)
LED: J4.2, L24.3 (DIN), U1.1 (TX)
unnamed: D1.2 (A), SW1.2
unnamed: D2.2 (A), SW2.2
unnamed: D3.2 (A), SW3.2
unnamed: D4.2 (A), SW4.2
unnamed: D5.2 (A), SW5.2
unnamed: D6.2 (A), SW6.2
unnamed: D7.2 (A), SW7.2
unnamed: D8.2 (A), SW8.2
unnamed: D9.2 (A), SW9.2
unnamed: D10.2 (A), SW10.2
unnamed: D11.2 (A), SW11.2
unnamed: D12.2 (A), SW12.2
unnamed: D13.2 (A), SW13.2
unnamed: D14.2 (A), SW14.2
unnamed: D15.2 (A), SW15.2
unnamed: D16.2 (A), SW16.2
unnamed: D17.2 (A), SW17.2
unnamed: D18.2 (A), SW18.2
unnamed: D19.2 (A), SW19.2
unnamed: D20.2 (A), SW20.2
unnamed: D21.2 (A), SW21.2
unnamed: J2.1, JP4.2 (B), JP8.2 (B)
unnamed: J2.2, JP3.2 (B), JP7.2 (B)
unnamed: J2.4, JP2.2 (B), JP6.2 (B)
unnamed: J2.5, JP1.2 (B), JP5.2 (B)
unnamed: J3.2, PSW1.2 (B)
unnamed: J1.A, JP9.2 (B)
unnamed: J1.B, JP10.2 (C)
unnamed: L1.4 (DIN), L2.2 (DOUT)
unnamed: L1.2 (DOUT), L7.4 (DIN)
unnamed: L2.4 (DIN), L8.2 (DOUT)
unnamed: L3.4 (DIN), L4.2 (DOUT)
unnamed: L3.2 (DOUT), L9.4 (DIN)
unnamed: L5.4 (DIN), L6.2 (DOUT)
unnamed: L10.4 (DIN), L16.2 (DOUT)
unnamed: L4.4 (DIN), L10.2 (DOUT)
unnamed: L5.2 (DOUT), L11.4 (DIN)
unnamed: L11.2 (DOUT), L17.4 (DIN)
unnamed: L12.4 (DIN), L18.2 (DOUT)
unnamed: L6.4 (DIN), L12.2 (DOUT)
unnamed: L7.2 (DOUT), L13.4 (DIN)
unnamed: L14.4 (DIN), L15.2 (DOUT)
unnamed: L8.4 (DIN), L14.2 (DOUT)
unnamed: L9.2 (DOUT), L15.4 (DIN)
unnamed: L16.4 (DIN), L19.2 (DOUT)
unnamed: L17.2 (DOUT), L20.4 (DIN)
unnamed: L18.4 (DIN), L21.2 (DOUT)
unnamed: L19.4 (DIN), L20.2 (DOUT)
unnamed: L21.4 (DIN), L27.1 (DOUT)
unnamed: L22.3 (DIN), L23.1 (DOUT)
unnamed: L22.1 (DOUT), L25.3 (DIN)
unnamed: L23.3 (DIN), L24.1 (DOUT)
unnamed: L25.1 (DOUT), L26.3 (DIN)
unnamed: L26.1 (DOUT), L27.3 (DIN)
RESET: RSW1.2, U1.22 (RST)
SCL: JP3.1 (A), JP6.1 (A), JP9.1 (A), R3.1, U1.6 (SCL)
SDA: JP4.1 (A), JP5.1 (A), JP10.3 (B), R4.2, U1.5 (SDA)
VCC: J1.D, J2.3, J4.3, L1.1 (VDD), L2.1 (VDD), L3.1 (VDD), L4.1 (VDD), L5.1 (VDD), L6.1 (VDD), L7.1 (VDD), L8.1 (VDD), L9.1 (VDD), L10.1 (VDD), L11.1 (VDD), L12.1 (VDD), L13.1 (VDD), L14.1 (VDD), L15.1 (VDD), L16.1 (VDD), L17.1 (VDD), L18.1 (VDD), L19.1 (VDD), L20.1 (VDD), L21.1 (VDD), L22.4 (VDD), L23.4 (VDD), L24.4 (VDD), L25.4 (VDD), L26.4 (VDD), L27.4 (VDD), R1.1, R3.2, R4.1, U1.21 (VCC)
col0: SW1.1, SW7.1, SW13.1, U1.20 (F4)
col1: SW2.1, SW8.1, SW14.1, U1.19 (F5)
col2: SW3.1, SW9.1, SW15.1, U1.18 (F6)
col3: SW4.1, SW10.1, SW16.1, SW19.1, U1.17 (F7)
col4: SW5.1, SW11.1, SW17.1, SW20.1, U1.16 (B1)
col5: SW6.1, SW12.1, SW18.1, SW21.1, U1.15 (B3)
row0: D1.1 (K), D2.1 (K), D3.1 (K), D4.1 (K), D5.1 (K), D6.1 (K), U1.7 (D4)
row1: D7.1 (K), D8.1 (K), D9.1 (K), D10.1 (K), D11.1 (K), D12.1 (K), U1.8 (C6)
row2: D13.1 (K), D14.1 (K), D15.1 (K), D16.1 (K), D17.1 (K), D18.1 (K), U1.9 (D7)
row3: D19.1 (K), D20.1 (K), D21.1 (K), U1.10 (E6)

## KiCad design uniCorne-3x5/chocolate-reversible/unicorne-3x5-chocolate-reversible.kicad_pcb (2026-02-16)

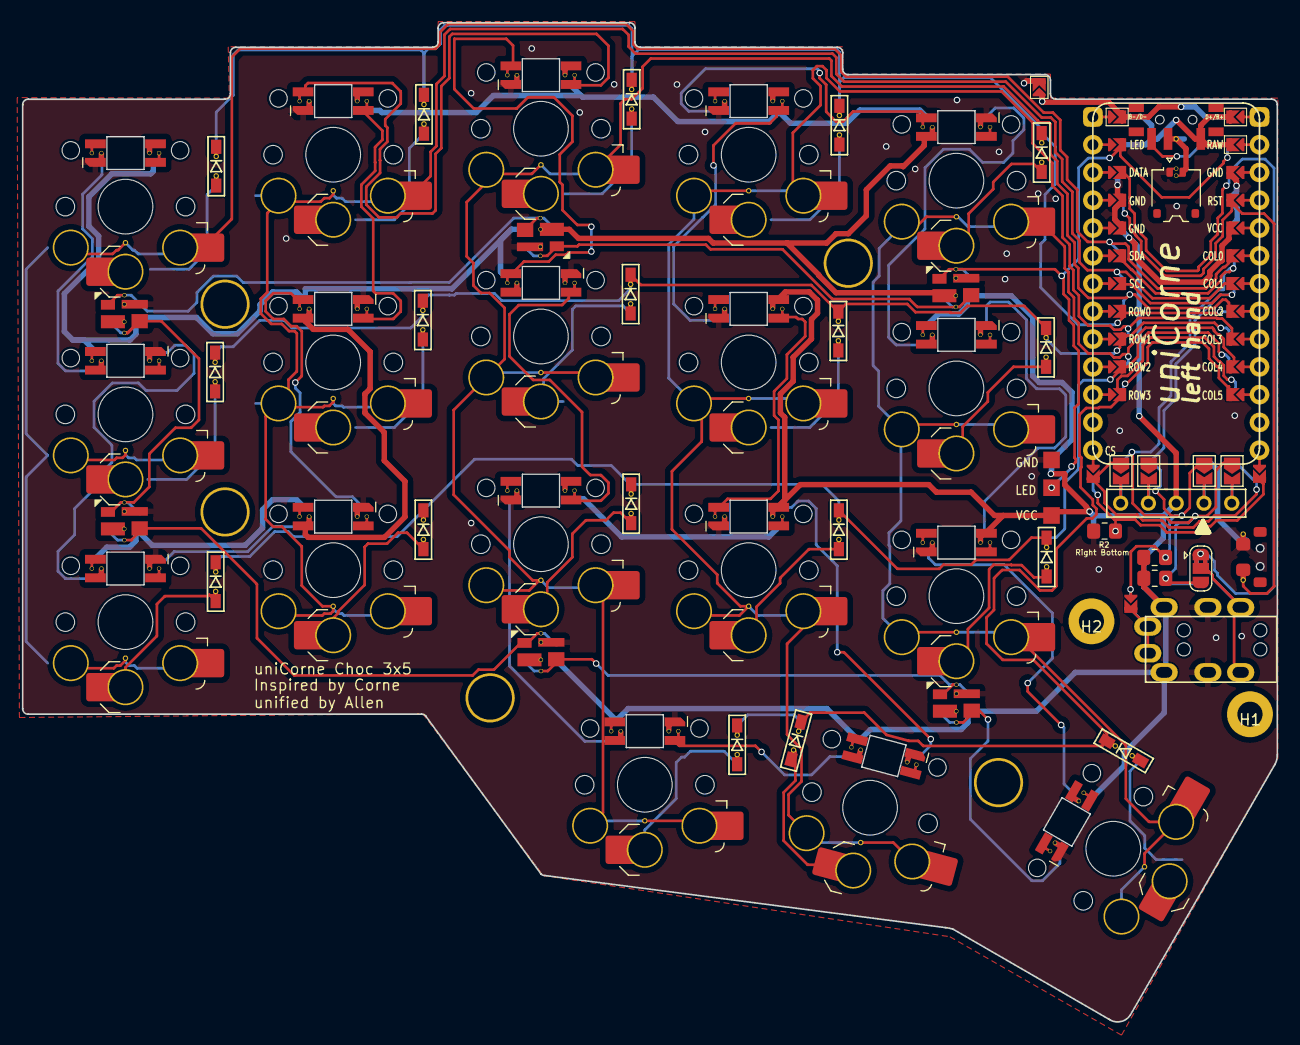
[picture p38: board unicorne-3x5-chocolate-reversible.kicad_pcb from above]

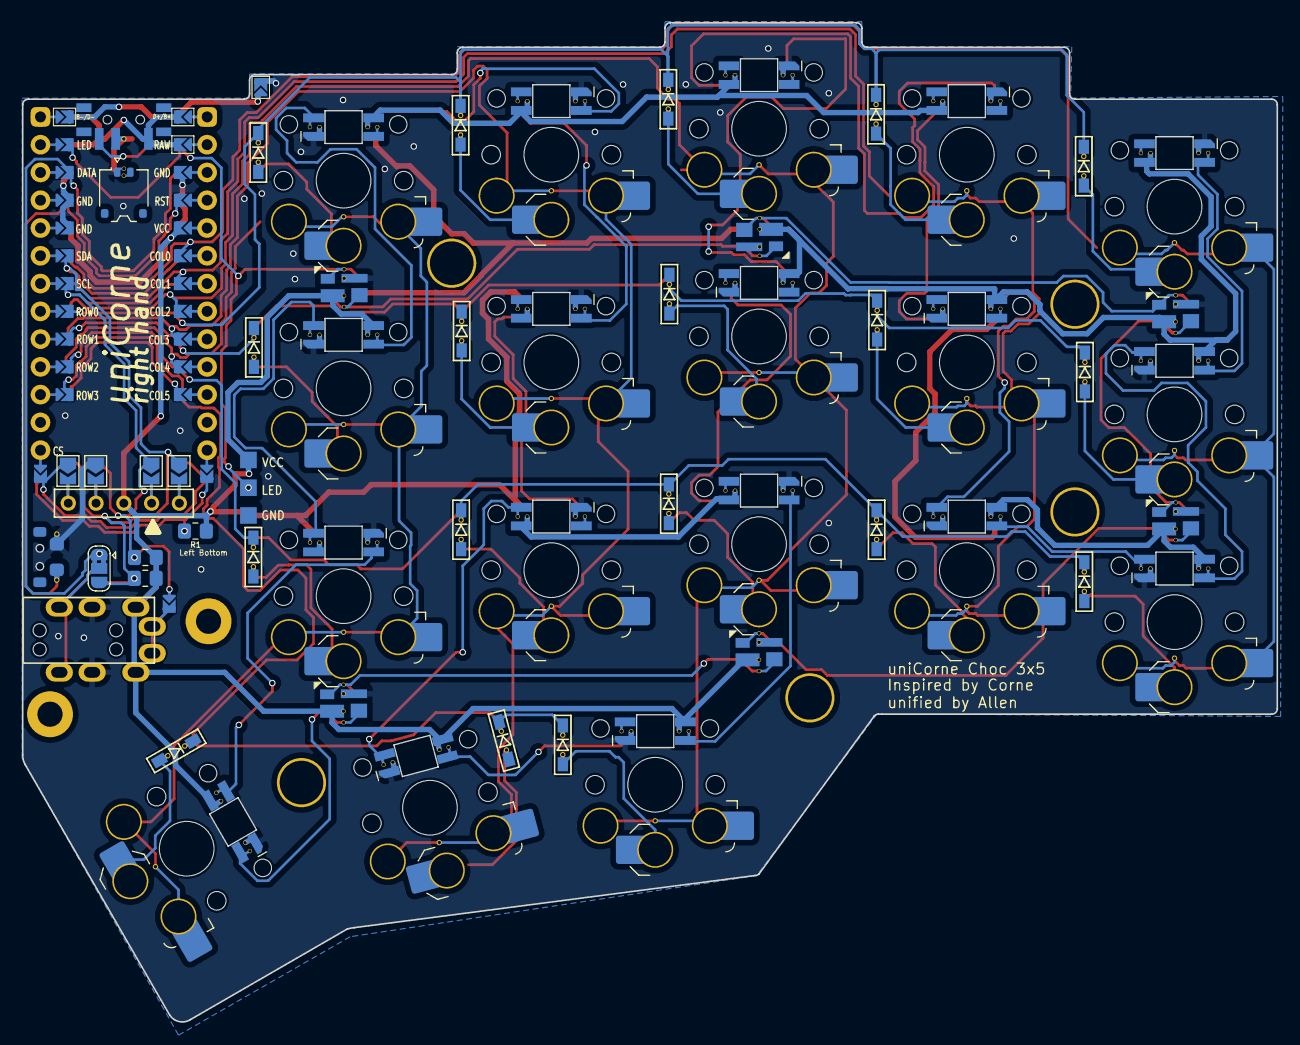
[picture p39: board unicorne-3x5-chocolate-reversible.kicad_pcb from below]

Board: 2 copper layers, 114.7 x 91.4 mm, 89 parts (30 on the bottom side), 68 nets.

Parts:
D1, D2, D3, D4, D5, D6, D7, D8, D9, D10, D11, D12, D13, D14, D15, D16, D17, D18: D; D3_SMD_rev
H1, H2: MountingHole; M2_Hole_TH
H3, H4, H5, H6, H7: MountingHole; M2_Hole_TH_Outside
J1: MJ-4PP-9; TRRS-PJ-320A-rev
J2: Conn_01x05; Nice!View
J3: Conn_01x02; Molex_Pico-EZmate_78171-0002_1x02-1MP_P1.20mm_Vertical_rev
J4: Conn_01x03; StripLED_rev
JP1, JP2, JP3, JP4, JP5, JP6, JP7, JP8: Jumper_2_Open; SolderJumper-2_P1.3mm_Open_TrianglePad1.0x1.5mm
JP9: Jumper_3_Bridged12; SolderJumper-3_P1.3mm_Bridged2Bar12_RoundedPad1.0x1.5mm_rev
JP10, JP11: SolderJumper-2_P1.3mm_Open_TrianglePad1.0x1.2mm_rev
L1, L2, L3, L4, L5, L6, L7, L8, L9, L10, L11, L12, L13, L14, L15, L16, L17, L18: SK6812MINI-E; LED_SK6812MINI-E_rev
L19, L20, L21, L22, L23, L24: SK6812MINI; LED_SK6812MINI_PLCC4_3.5x3.5mm_P1.75mm_rev_all
PSW1: SW_SPDT; SW_SPDT_PCM12_reversible
R1, R2: 10k; R_0805_2012Metric_Pad1.20x1.40mm_HandSolder
R3, R4: 4.7k; R_0805_2012Metric_Pad1.20x1.40mm_HandSolder_rev
RSW1: SMT 2X4X3.5MM Tactile Tact Push Button; SMT 2X4X3.5MM Tactile Tact Push Button rev
SW1, SW2, SW3, SW4, SW5, SW6, SW7, SW8, SW9, SW10, SW11, SW12, SW13, SW14, SW15, SW16, SW17: SW_CHOC_HS; SW_choc_v1_v2_HS_1u_reversible
SW18: SW_CHOC_HS; SW_choc_v1_v2_HS_1.5u_reversible
U1: ProMicro-ish; ProMicro-ish-dn-rev-unrouted_3x5

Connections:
B-/D-: JP11.1 (A), U1.26 (B-/D-)
BAT+: PSW1.1 (A), U1.24 (RAW), U1.25 (D+/B+)
CS: JP1.1 (A), JP8.1 (A), U1.12 (B5)
DATA: JP9.1 (A), U1.2 (RX)
GND: J1.C, J3.1, J4.1, JP2.1 (A), JP7.1 (A), JP11.2 (B), L1.3 (VSS), L2.3 (VSS), L3.3 (VSS), L4.3 (VSS), L5.3 (VSS), L6.3 (VSS), L7.3 (VSS), L8.3 (VSS), L9.3 (VSS), L10.3 (VSS), L11.3 (VSS), L12.3 (VSS), L13.3 (VSS), L14.3 (VSS), L15.3 (VSS), L16.3 (VSS), L17.3 (VSS), L18.3 (VSS), L19.2 (VSS), L20.2 (VSS), L21.2 (VSS), L22.2 (VSS), L23.2 (VSS), L24.2 (VSS), R2.1, RSW1.2, U1.3 (GND), U1.4 (GND), U1.23 (GND)
IS_LEFT: R1.2, R2.2, U1.13 (B6)
LED: J4.2, L21.3 (DIN), U1.1 (TX)
unnamed: D1.2 (A), SW1.2
unnamed: D2.2 (A), SW2.2
unnamed: D3.2 (A), SW3.2
unnamed: D4.2 (A), SW4.2
unnamed: D5.2 (A), SW5.2
unnamed: D6.2 (A), SW6.2
unnamed: D7.2 (A), SW7.2
unnamed: D8.2 (A), SW8.2
unnamed: D9.2 (A), SW9.2
unnamed: D10.2 (A), SW10.2
unnamed: D11.2 (A), SW11.2
unnamed: D12.2 (A), SW12.2
unnamed: D13.2 (A), SW13.2
unnamed: D14.2 (A), SW14.2
unnamed: D15.2 (A), SW15.2
unnamed: D16.2 (A), SW16.2
unnamed: D17.2 (A), SW17.2
unnamed: D18.2 (A), SW18.2
unnamed: J2.1, JP4.2 (B), JP8.2 (B)
unnamed: J2.2, JP3.2 (B), JP7.2 (B)
unnamed: J2.4, JP2.2 (B), JP6.2 (B)
unnamed: J2.5, JP1.2 (B), JP5.2 (B)
unnamed: J3.2, PSW1.2 (B)
unnamed: J1.B, JP9.2 (C)
unnamed: J1.A, JP10.2 (B)
unnamed: L1.4 (DIN), L6.2 (DOUT)
unnamed: L2.4 (DIN), L3.2 (DOUT)
unnamed: L2.2 (DOUT), L7.4 (DIN)
unnamed: L3.4 (DIN), L8.2 (DOUT)
unnamed: L4.4 (DIN), L5.2 (DOUT)
unnamed: L4.2 (DOUT), L9.4 (DIN)
unnamed: L10.4 (DIN), L15.2 (DOUT)
unnamed: L5.4 (DIN), L10.2 (DOUT)
unnamed: L11.4 (DIN), L12.2 (DOUT)
unnamed: L6.4 (DIN), L11.2 (DOUT)
unnamed: L7.2 (DOUT), L12.4 (DIN)
unnamed: L13.4 (DIN), L16.2 (DOUT)
unnamed: L8.4 (DIN), L13.2 (DOUT)
unnamed: L9.2 (DOUT), L14.4 (DIN)
unnamed: L14.2 (DOUT), L17.4 (DIN)
unnamed: L15.4 (DIN), L18.2 (DOUT)
unnamed: L16.4 (DIN), L17.2 (DOUT)
unnamed: L18.4 (DIN), L24.1 (DOUT)
unnamed: L19.3 (DIN), L20.1 (DOUT)
unnamed: L19.1 (DOUT), L22.3 (DIN)
unnamed: L20.3 (DIN), L21.1 (DOUT)
unnamed: L22.1 (DOUT), L23.3 (DIN)
unnamed: L23.1 (DOUT), L24.3 (DIN)
RESET: RSW1.1, U1.22 (RST)
SCL: JP3.1 (A), JP6.1 (A), JP10.1 (A), R3.1, U1.6 (SCL)
SDA: JP4.1 (A), JP5.1 (A), JP9.3 (B), R4.2, U1.5 (SDA)
VCC: J1.D, J2.3, J4.3, L1.1 (VDD), L2.1 (VDD), L3.1 (VDD), L4.1 (VDD), L5.1 (VDD), L6.1 (VDD), L7.1 (VDD), L8.1 (VDD), L9.1 (VDD), L10.1 (VDD), L11.1 (VDD), L12.1 (VDD), L13.1 (VDD), L14.1 (VDD), L15.1 (VDD), L16.1 (VDD), L17.1 (VDD), L18.1 (VDD), L19.4 (VDD), L20.4 (VDD), L21.4 (VDD), L22.4 (VDD), L23.4 (VDD), L24.4 (VDD), R1.1, R3.2, R4.1, U1.21 (VCC)
col0: SW1.1, SW6.1, SW11.1, U1.20 (F4)
col1: SW2.1, SW7.1, SW12.1, U1.19 (F5)
col2: SW3.1, SW8.1, SW13.1, SW16.1, U1.18 (F6)
col3: SW4.1, SW9.1, SW14.1, SW17.1, U1.17 (F7)
col4: SW5.1, SW10.1, SW15.1, SW18.1, U1.16 (B1)
row0: D1.1 (K), D2.1 (K), D3.1 (K), D4.1 (K), D5.1 (K), U1.7 (D4)
row1: D6.1 (K), D7.1 (K), D8.1 (K), D9.1 (K), D10.1 (K), U1.8 (C6)
row2: D11.1 (K), D12.1 (K), D13.1 (K), D14.1 (K), D15.1 (K), U1.9 (D7)
row3: D16.1 (K), D17.1 (K), D18.1 (K), U1.10 (E6)

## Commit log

2024-01-13 Top plate - PCB
    [unicorne-3x5-top-plate.kicad_pcb]
2024-01-14 amend PCB
    [unicorne-cherry-mx-3x5-reversible.kicad_pcb, unicorne-cherry-mx-3x5-reversible.kicad_sch, unicorne-chocolate-3x5-reversible.kicad_pcb]
2024-01-15 amend silkscreen
    [unicorne-cherry-mx-3x5-reversible.kicad_pcb, unicorne-chocolate-3x5-reversible.kicad_pcb]
2024-02-02 hardware handedness
    [unicorne-3x5-top-plate-hybrid.kicad_pcb, unicorne-cherry-mx-3x5-reversible.kicad_pcb, unicorne-cherry-mx-3x5-reversible.kicad_sch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]
2024-02-03 small tweak
    [unicorne-cherry-mx-3x5-reversible.kicad_pcb, unicorne-chocolate-3x5-reversible.kicad_pcb, unicorne-chocolate-3x5-reversible.kicad_sch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]
2024-02-03 add kiplot
    [unicorne-hybrid-mx-3x5-reversible.kicad_pcb]
2024-02-03 added bottom plate
    [unicorne-3x5-bottom-plate.kicad_pcb, unicorne-3x5-bottom-plate.kicad_sch]
2024-02-04 amend cases
    [unicorne-cherry-mx-3x5-left-cnc.step, unicorne-cherry-mx-3x5-left.step, unicorne-cherry-mx-3x5-left.stl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]
2024-02-05 reorg structure
    [unicorne-3x5-cherry-mx-reversible.kicad_pcb, unicorne-3x5-cherry-mx-reversible.kicad_sch, unicorne-3x5-chocolate-reversible.kicad_pcb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]
2024-02-06 uniCorne 3x6 cherry-mx
    [unicorne-3x6-cherry-mx-reversible.kicad_pcb, unicorne-3x6-cherry-mx-reversible.kicad_sch]
2024-02-06 uniCorne 3x6 chocolate
    [unicorne-3x5-bottom-plate.kicad_pcb, unicorne-3x6-cherry-mx-reversible.kicad_pcb, unicorne-3x6-chocolate-reversible.kicad_pcb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]
2024-02-06 uniCorne 3x6 hybrid
    [unicorne-3x6-hybrid-mx-reversible.kicad_pcb, unicorne-3x6-hybrid-mx-reversible.kicad_sch]
2024-02-07 Amended hybrid 3x6
    [unicorne-3x6-hybrid-mx-reversible.kicad_pcb, unicorne-3x6-hybrid-mx-reversible.kicad_sch]
2024-02-07 amended hybrid 3x5
    [unicorne-3x5-hybrid-mx-reversible.kicad_pcb, unicorne-3x5-hybrid-mx-reversible.kicad_sch]
2024-02-07 amended cherry mx 3x5
    [unicorne-3x5-cherry-mx-reversible.kicad_pcb, unicorne-3x5-cherry-mx-reversible.kicad_sch]
2024-02-07 amended chocolate 3x5
    [unicorne-3x5-cherry-mx-reversible.kicad_pcb, unicorne-3x5-chocolate-reversible.kicad_pcb, unicorne-3x5-chocolate-reversible.kicad_sch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]
2024-02-09 added plates
    [unicorne-3x5-top-plate.kicad_pcb, unicorne-3x6-bottom-plate.kicad_pcb, unicorne-3x6-bottom-plate.kicad_sch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]
2024-02-10 amended cases
    [unicorne-3x5-bottom-plate.kicad_pcb, unicorne-3x5-bottom-plate.kicad_sch, unicorne-3x5-top-plate-hybrid.kicad_pcb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]
2024-02-11 fix typo
    [unicorne-3x5-top-plate-hybrid.kicad_pcb, unicorne-3x6-top-plate-hybrid.kicad_pcb]
2024-02-15 added case for 3x6
    [uniCorne-cherry-mx-3x6-left.step, uniCorne-cherry-mx-3x6-left.stl, uniCorne-cherry-mx-3x6-right.step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]
2024-02-18 added github actions
    [uniCorne-cherry-mx-3x5-left.step, uniCorne-cherry-mx-3x5-left.stl, uniCorne-cherry-mx-3x5-right.step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]
2024-02-25 amended footprint for LED
    [unicorne-3x5-cherry-mx-reversible.kicad_pcb, unicorne-3x5-chocolate-reversible.kicad_pcb, unicorne-3x5-hybrid-mx-reversible.kicad_pcb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]
2024-03-03 fixed footprint for promicro-ish 3x6
    [unicorne-3x5-cherry-mx-reversible.kicad_pcb, unicorne-3x5-cherry-mx-reversible.kicad_sch, unicorne-3x5-chocolate-reversible.kicad_pcb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]
2024-06-17 Bug fix scl (#3)
    * fixed 3x5 hyprid mx
    * fixed 3x5
    * fixed 3x6
    [unicorne-3x5-cherry-mx-reversible.kicad_pcb, unicorne-3x5-cherry-mx-reversible.kicad_sch, unicorne-3x5-chocolate-reversible.kicad_pcb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]
2024-09-19 added fusion files (#4)
    [uniCorne-cherry-mx-3x5-CR2-25T.f3z, uniCorne-cherry-mx-3x6-CR2-25T.f3z, uniCorne-chocolate-3x5-CR2-25T.f3z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]
2024-10-02 Docs (#5)
    * added build guide
    * correct link
    [unicorne-3x5-bottom-plate.kicad_pcb]
2024-10-26 Docs / KiCad8 (#12)
    * KiCAD 8
    * KiCad8 for plates
    * Update Footprints
    * Update README.md
    * added more docs
    [unicorne-3x5-bottom-plate.kicad_pcb, unicorne-3x5-bottom-plate.kicad_sch, unicorne-3x5-cherry-mx-reversible.kicad_pcb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]
2026-02-16 fixed SDA/SCL shorted (#15)
    * fixed SDA/SCL shorted
    * fixed workflows
    * KiCad v2_k9
    [unicorne-3x5-cherry-mx-reversible.kicad_pcb, unicorne-3x5-chocolate-reversible.kicad_pcb, unicorne-3x5-hybrid-mx-reversible.kicad_pcb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]
